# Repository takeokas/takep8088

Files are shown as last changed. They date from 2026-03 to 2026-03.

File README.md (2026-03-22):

# takep8088
8088 Single Board Computer  

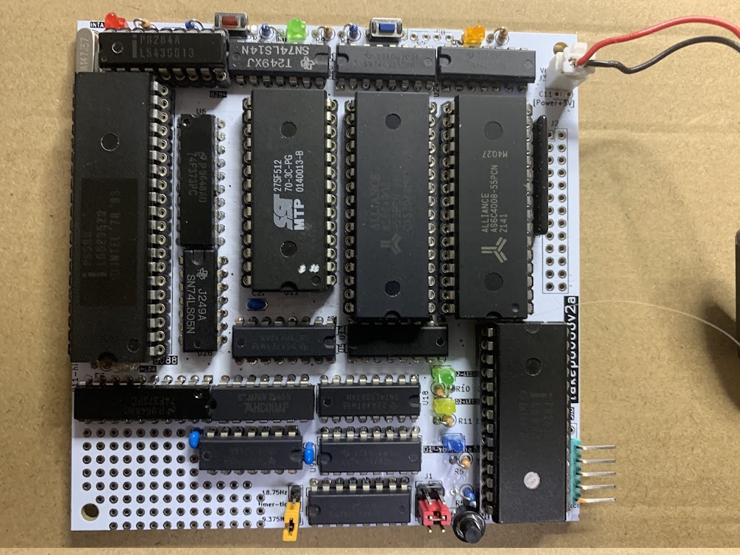
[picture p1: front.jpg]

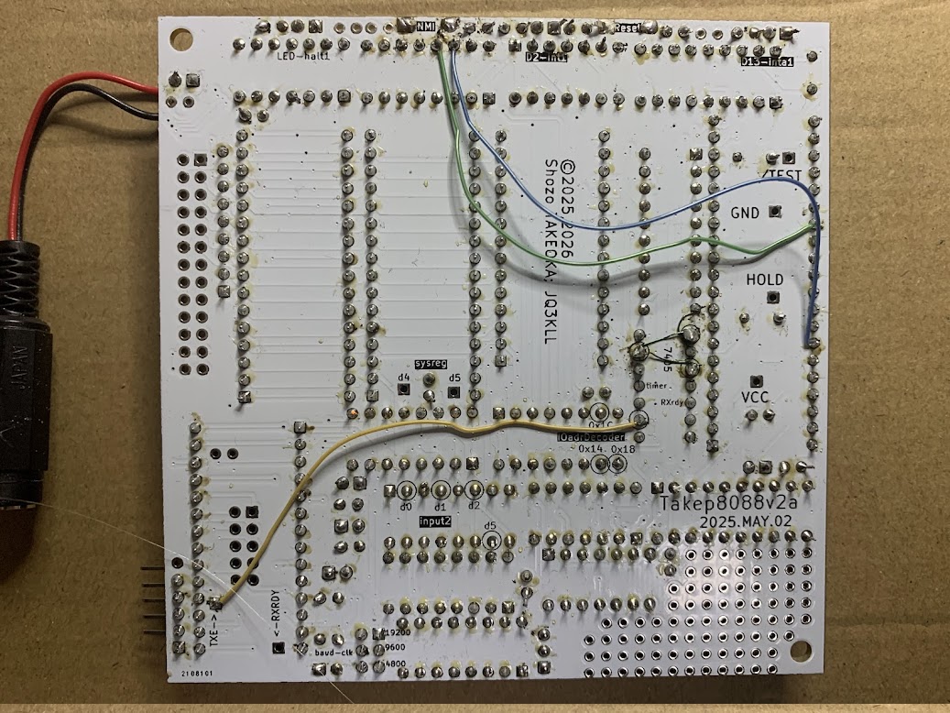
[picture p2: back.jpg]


## Spec  
- S-RAM 1MBytes  
--  全メモリ空間  
-- AS6C4008-55PCN (512KW×8bit)2チップ  
-- リセット直後は、メモリ空間の後半 512K は、ROM  
-- 出力ポートのアクセスで、後半512KをROM/RAM切り替え  

- ROM 64Bytes  
-- SST 27SF512(EEPROM)  
-- 27C512互換であれば使用可能、2764あたりからそのまま差し込めるはず  

- SIO 8251(USART)  
-- ジャンパ J1 で、ボーレート用クロックの周波数を選択可能  
-- 秋月で販売されている FTDI USBシリアル変換ケーブル(5V) が直接 差せる  
--  https://akizukidenshi.com/catalog/g/g105841/    

- フリーランニング・タイマ  
  18.75Hz / 9.375Hz を JP1 で、選択可能  

- Crystal 14.7456MHz  
-- 8251(USART) の baud rate generation に、いい感じの周波数  
-- CPU は、約 4.9MHz で動作  
-- 周辺IOのクロックは、約2.45MHz  

## ボード  


- ジャンパ J1  
-- 8251(USART)のボーレート・ジェネレータの周波数選択  
  19200/9600/4800 bps  (f/1の場合)  
  
- ジャンパ JP1  
-- フリーランニング・タイマの周期選択  
  18.75Hz / 9.375Hz

- ワイヤリング  
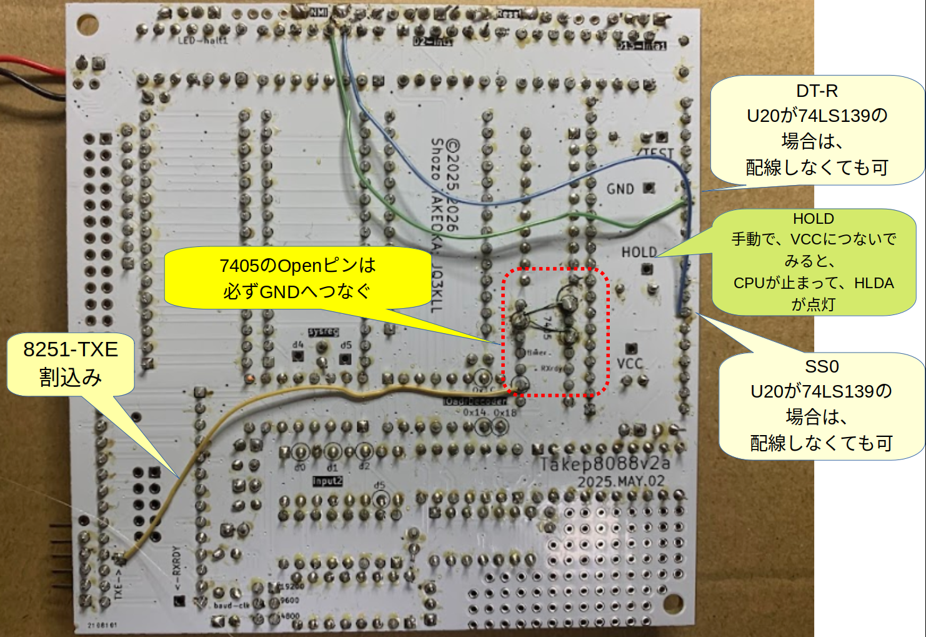
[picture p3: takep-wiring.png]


-- 8251 TX Empty割込みを使用する場合は、7405 の空き入力端子に、8251-TXE を接続する  
-- 7405 の空き入力ピンは、(手配線などで) 必ず GND へ、接続する。さもないと、Interrupt Enableした途端に、割込みが発生する。  
-- U20 74139が、74HC139 のときは、空き入力ピンを、DT-R、SS0 に接続すること。74LS139など TTL のときは、open のママでも支障ない。  

※ワイヤがあるのは、設計どおり  
-- PCBレイアウト中に、引き回しを諦めただけ…orz  

## 回路
### 7405: 割込み 要求  
-- 7405の入力は、反転されて、すべてワイアードORして反転して、8088のINT(割込み要求)に接続  
-- 7405のopenな端子は、自分で(手ハンダで?)、PullDownの必要あり  
-- 後から付けた機器からの割込み要求は、7405の空き端子に接続するとよい  

### 8251 TX Empty 割込み 要求  
-- 8251の RX割込みは、PCBで7405に接続済み  
-- 8251の TXE(empty)割込み使うよね!  
-- 自分で、7405 に配線してください ＼(^^;／  
-- PCBのレイアウトを諦めた=それが設計だっ  

### 余りゲート  
-- U1,74LS14: B(3,4),C(5,6),F(13,12)  
-- U12,74LS00: A(1,2,3),B(4,5,6)  
-- U24,74LS00: C(10,9,8),D(13,12,11)  
-- U23,74LS74: B(8-13)  

## IOポート  
###  IO port address  

   00-03 : usart0 (rw) USART レジスタ; 通常 00と01 を使用する  
   04-07 : sw1 (rd);  D0: SWの値を読む, D1: timerIRQ の確認  
   08-0B : timer-irq-clr (wr); timer IRQのクリア  
   0C-0F : sysreg (wr),D0:/rom0-ena=0でROM, 1でRAM1, D1:timer-int-ena=1でtimer割込み可, D2:led2, D3:led3  
  
   10-13 : inport2(rd),  D0: U18[2pin]=NC, D1:U18[4pin]=NC;U18=74LS367  
   14-17 :   
   18-1B :   
   1C-1F :   
   
### IO port 説明  
- sysreg (WR) 0x0C ; U5,74LS174  
-- D0: /rom0-ena (reset:0), 0:ROM0 / 1:RAM1 (メモリ空間後半 A19==1 を ROM/RAM切り替え)  
-- D1: timer-int-ena (reset:0), 0:disable / 1:enable  
-- D2: LED2 (resetで0, 点灯)  
-- D3: LED3 (resetで0, 点灯)  
-- D4: (U5 Q4)Open  
-- D5: (U5 Q5)Open  
  
- SW1 (RD) 0x04  
-- D0: SW  
-- D1 : free running timer IRQ 読み出し  
  
- timer-irq-clr  (WR) 0x08  
-- free running timer INT clear  
-- 1/(2^18) カウンタ割り込みクリア  
  
- inport2(rd) 0x10  
-- U18=74LS367  
-- D0: U18[2pin]=NC, D1:U18[4pin]=NC;  
-- D2: U18[6pin]=NC, D5:U18[10pin]=NC;   
※D3,D4 は飛ばしている(配線の困難性から)

## その他  
- HOLD を、Vcc に、手動で接続してみると、CPU の実行が停止し、HLDA LEDが点灯する  
- HOLD を使用する機器は、HOLD 端子に接続するとよい(PCB では、Pull Downしているのみ)
- 2026/MAR/20 「Kernel/VM探検隊＠つくば No3」での、発表資料  
--  https://www.slideshare.net/slideshow/tht-8088-single-board-computer-with-amd-8088-bought-at-junk-shop-in-1989/286593537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
-

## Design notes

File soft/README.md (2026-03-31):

# program loader via Xmodem  
## プログラムについて  
- nasm でアセンブル可能  
- xmodemプログラムは、fff00h に置く。ROMにはそうなるように書きこむ  
- xmodem は  
  - プログラムがスタートすると「*」を1つだけUSARTから送信  
  - ロードされるバイナリは 00400h{0040h:0000h} から置かれる  
  - ロードが終了すると、0040h:0000h 番地へ far jump {cs=0040h,pc=0000h}
- xmodem100 は  
  - プログラムがスタートすると「#」を1つだけUSARTから送信  
  - ロードされるバイナリは 00500h から置かれる  
  - ロードが終了すると、0040h:0100h 番地へ far jmp {cs=0040h,pc=0100h}
- xmodem プログラムのスタックは、020000h から、前へ伸びる  

## 使い方
- ホスト・マシンで xmodem 送信を起動後、takep8088 をリセットすると、xmodem 通信が始まる
  - 通信速度は 9600 bps。 J1 ジャンパは、真ん中(3-4)を選択  
  - 「*」または「#」がホストに送られるが、問題ない  
- xmodemが開始していない間、SW1 を押下すると、LED2 が点灯する

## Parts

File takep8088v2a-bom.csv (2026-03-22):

# | Reference | Qty | Value | Comment | 購入URL | Footprint | DNP
1 | C1, C2, C3, C4, C5, C6, C7, C8, C9 | 9 | C |  |  | Capacitor_THT:C_Disc_D3.0mm_W2.0mm_P2.50mm
2 | C10 | 1 | 10uF |  |  | Capacitor_THT:C_Disc_D3.0mm_W2.0mm_P2.50mm
3 | C11 | 1 | CP |  |  | Capacitor_THT:C_Disc_D3.4mm_W2.1mm_P2.50mm
4 | D1-rom0ena1, D2-int1, D2-LED2, D2-LED3, D11-hlda1, D13-inta1, LED-halt1 | 7 | LED |  |  | LED_THT:LED_D1.8mm_W3.3mm_H2.4mm
5 | J1 | 1 | HEADER_3x2,PH-2x3SG | USART ボーレート・ジェネレータ入力周波数 選択 | https://akizukidenshi.com/catalog/g/g116883/ | Connector_PinHeader_2.54mm:PinHeader_2x03_P2.54mm_Vertical
6 | J2 | 1 | HEADER_13x2 | IO拡張コネクタ。適当に好きなもの |  | Connector_PinHeader_2.54mm:PinHeader_2x13_P2.54mm_Vertical
7 | J2-scc0 | 1 | HEADER_6,PH-1X6RG(2) | SIOコネクタ。FTDI USBシリアル・ケーブルが適合 | https://akizukidenshi.com/catalog/g/g105336/ | Connector_PinHeader_2.54mm:PinHeader_1x06_P2.54mm_Vertical
8 | J3 | 1 | HEADER_2 | +5V電源入力。適当に好きなもの |  | Connector_PinHeader_2.54mm:PinHeader_2x01_P2.54mm_Vertical
9 | J4, J5, J6, J7, J-HOLD1, J-TEST1, J-VCC1, J-VCC2 | 8 | - | test pointなので、何も実装しない
10 | J4-scc0 | 1 | - | test pointなので、何も実装しない |  | Connector_PinHeader_2.54mm:PinHeader_2x05_P2.54mm_Vertical
11 | JP1 | 1 | HEADER_1x3,PH-1X3SG | free running timerのレート選択 | https://akizukidenshi.com/catalog/g/g103949/ | Connector_PinHeader_2.54mm:PinHeader_1x03_P2.54mm_Vertical
12 | R1, R2, R5, R12 | 4 | R,10K |  |  | Resistor_THT:R_Axial_DIN0207_L6.3mm_D2.5mm_P2.54mm_Vertical
13 | R3, R4 | 2 | R,4.7K |  |  | Resistor_THT:R_Axial_DIN0204_L3.6mm_D1.6mm_P5.08mm_Horizontal
14 | R6, R7, R8, R9, R10, R11, R13 | 7 | R,330 |  |  | Resistor_THT:R_Axial_DIN0207_L6.3mm_D2.5mm_P2.54mm_Vertical
15 | RN1 | 1 | R_Network08 |  |  | Resistor_THT:R_Array_SIP9
16 | SW1 | 1 | TVBP06-B043CU-B | Reset | https://akizukidenshi.com/catalog/g/g108214/ | Button_Switch_THT:SW_PUSH_1P1T_6x3.5mm_H5.0_APEM_MJTP1250
17 | SW2 | 1 | TVBP06-B043CU-B | NMI_SW | https://akizukidenshi.com/catalog/g/g108214/ | Button_Switch_THT:SW_PUSH_1P1T_6x3.5mm_H5.0_APEM_MJTP1250
18 | U1 | 1 | 74LS14 |  |  | Package_DIP:DIP-14_W7.62mm
19 | U2, U6 | 2 | 74LS373 |  |  | Package_DIP:DIP-20_W7.62mm
20 | U3 | 1 | 8088 |  | https://wakamatsu.biz/products/detail/455907 | Package_DIP:DIP-40_W15.24mm_Socket
21 | U4, U7 | 2 | AS6C4008 | Aliexpressで買っても、およそ大丈夫 |  | Package_DIP:DIP-32_W15.24mm
22 | U5 | 1 | 74LS174 | 74HC174でも可 |  | Package_DIP:DIP-16_W7.62mm
23 | U8 | 1 | 8251A |  |  | Package_DIP:DIP-28_W15.24mm
24 | U9, U10 | 2 | 4040 |  |  | Package_DIP:DIP-16_W7.62mm
25 | U11 | 1 | 27C512 |  |  | Package_DIP:DIP-28_W15.24mm
26 | U12, U14 | 2 | 74HC00
27 | U13 | 1 | 74LS138 |  |  | Package_DIP:DIP-16_W7.62mm
28 | U15 | 1 | 8284 |  | https://wakamatsu.biz/products/detail/456508 | Package_DIP:DIP-18_W7.62mm
29 | U18 | 1 | 74LS367 |  |  | Package_DIP:DIP-16_W7.62mm
30 | U20 | 1 | 74LS139 | 一部入力ピンがopenなので、必ずLS。または、「役立たない配線」をするなら、LSでも可 |  | Package_DIP:DIP-16_W7.62mm
31 | U23 | 1 | 74HC74 |  |  | Package_DIP:DIP-14_W7.62mm
32 | U26 | 1 | 74LS05 | HCでも可。LSであっても、空き入力ピンは、必ずLoにすること。 |  | Package_DIP:DIP-14_W7.62mm
33 | Y1 | 1 | Crystal,14.7456MHz |  |  | Crystal:Crystal_HC49-4H_Vertical
34 | U24 | 1 | 74LS00 | 一部入力ピンがopenなので、必ずLS
35 | J6-SW1 | 1 |  | 適当なスイッチを無理やり取付ける

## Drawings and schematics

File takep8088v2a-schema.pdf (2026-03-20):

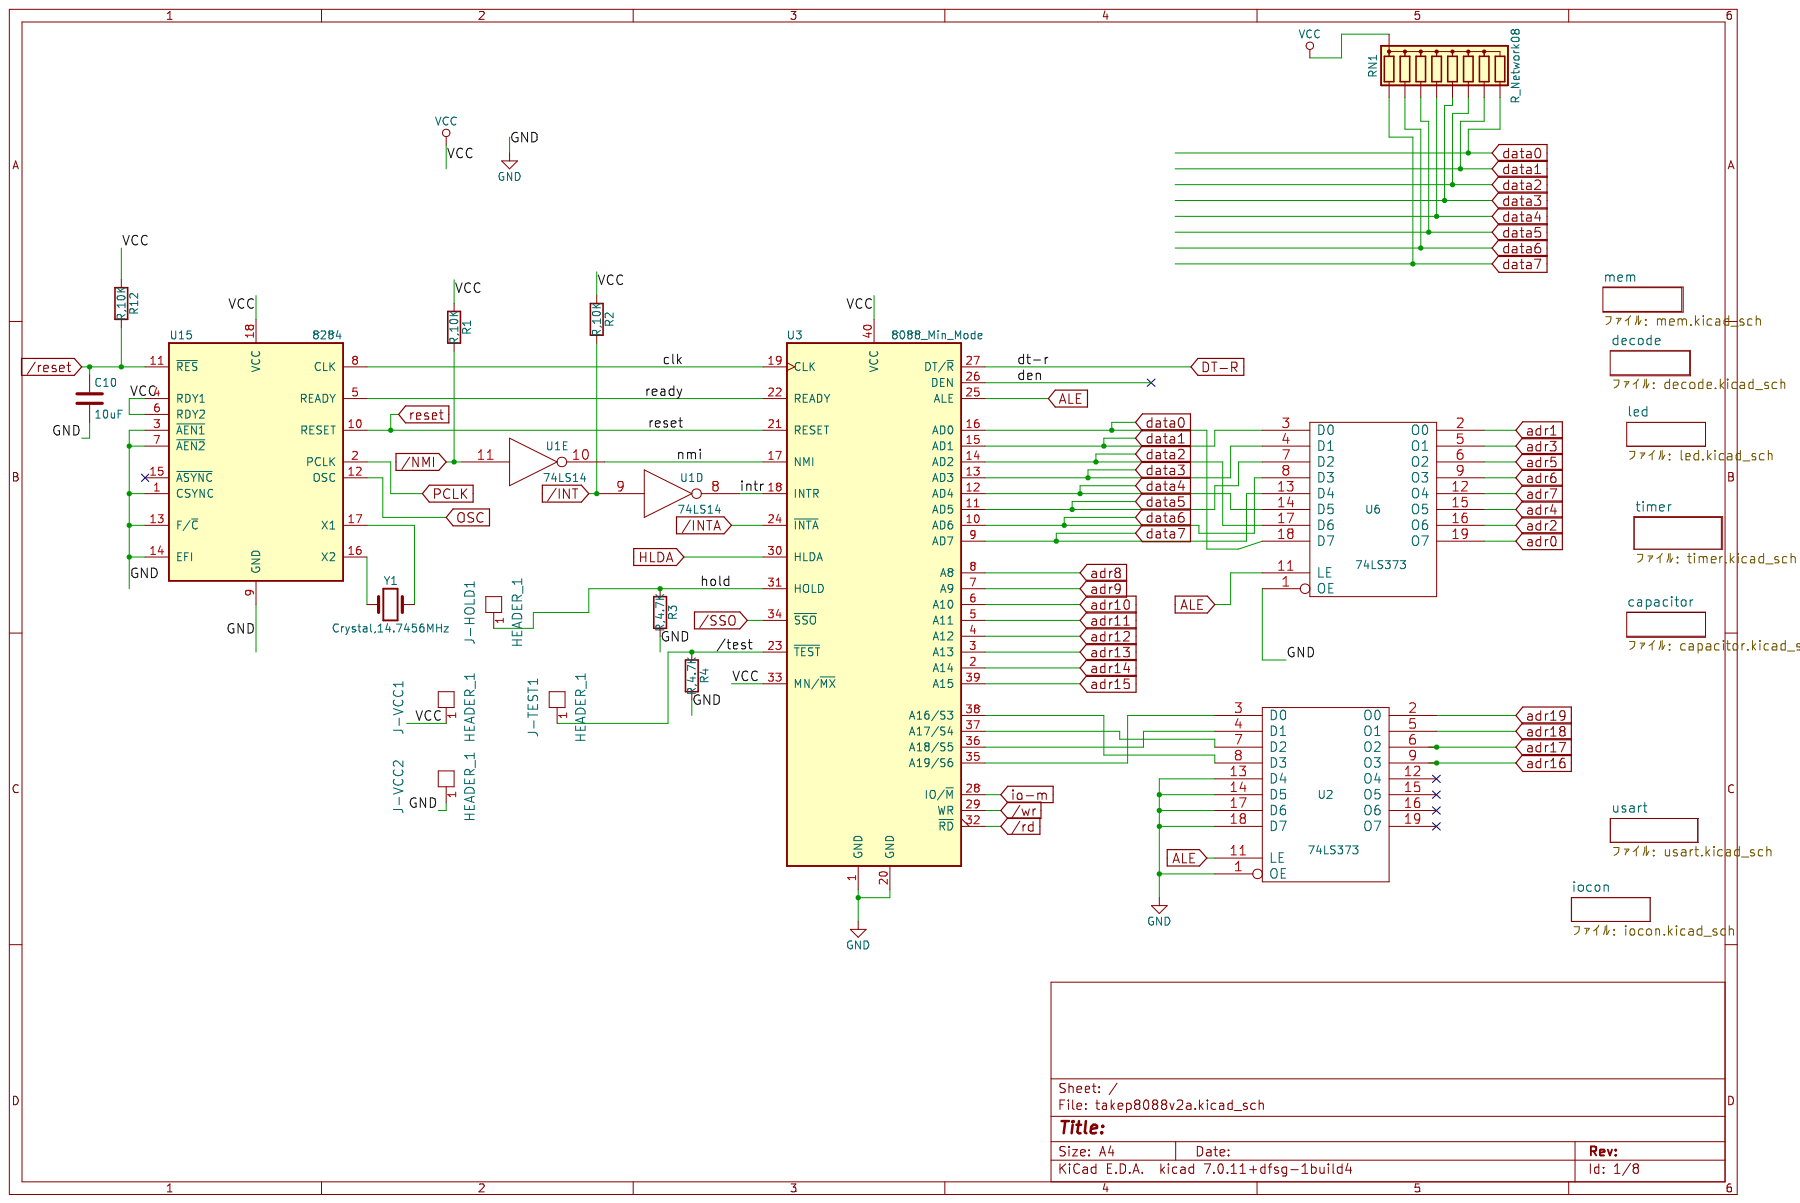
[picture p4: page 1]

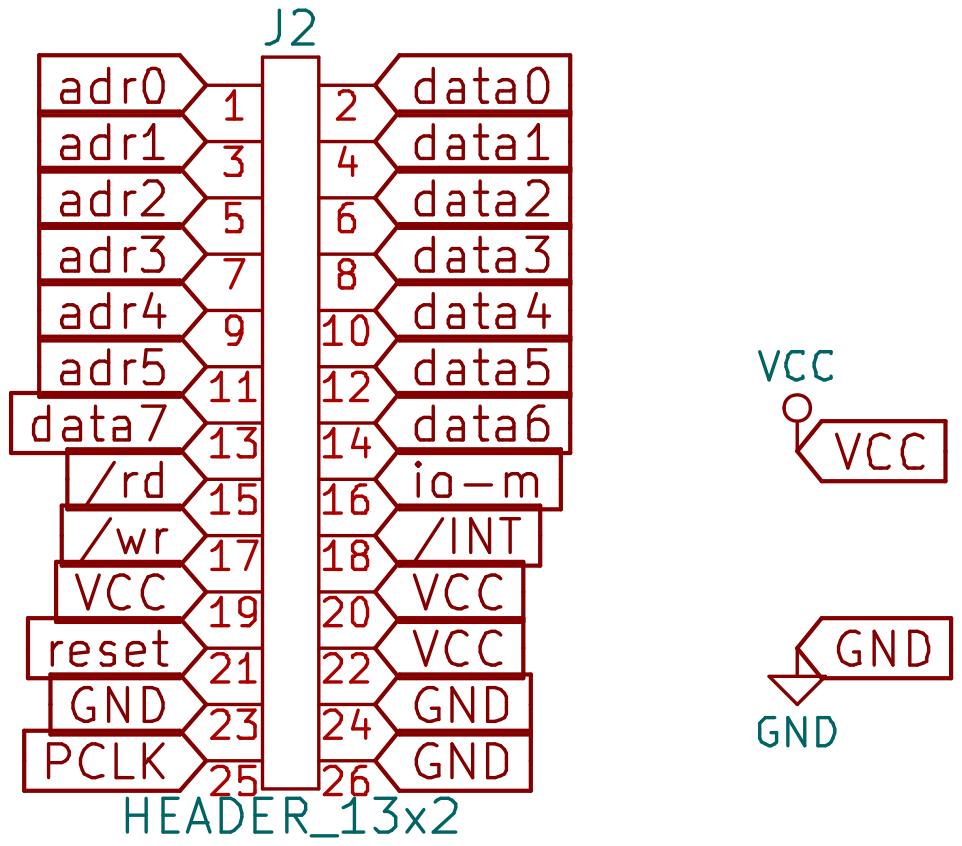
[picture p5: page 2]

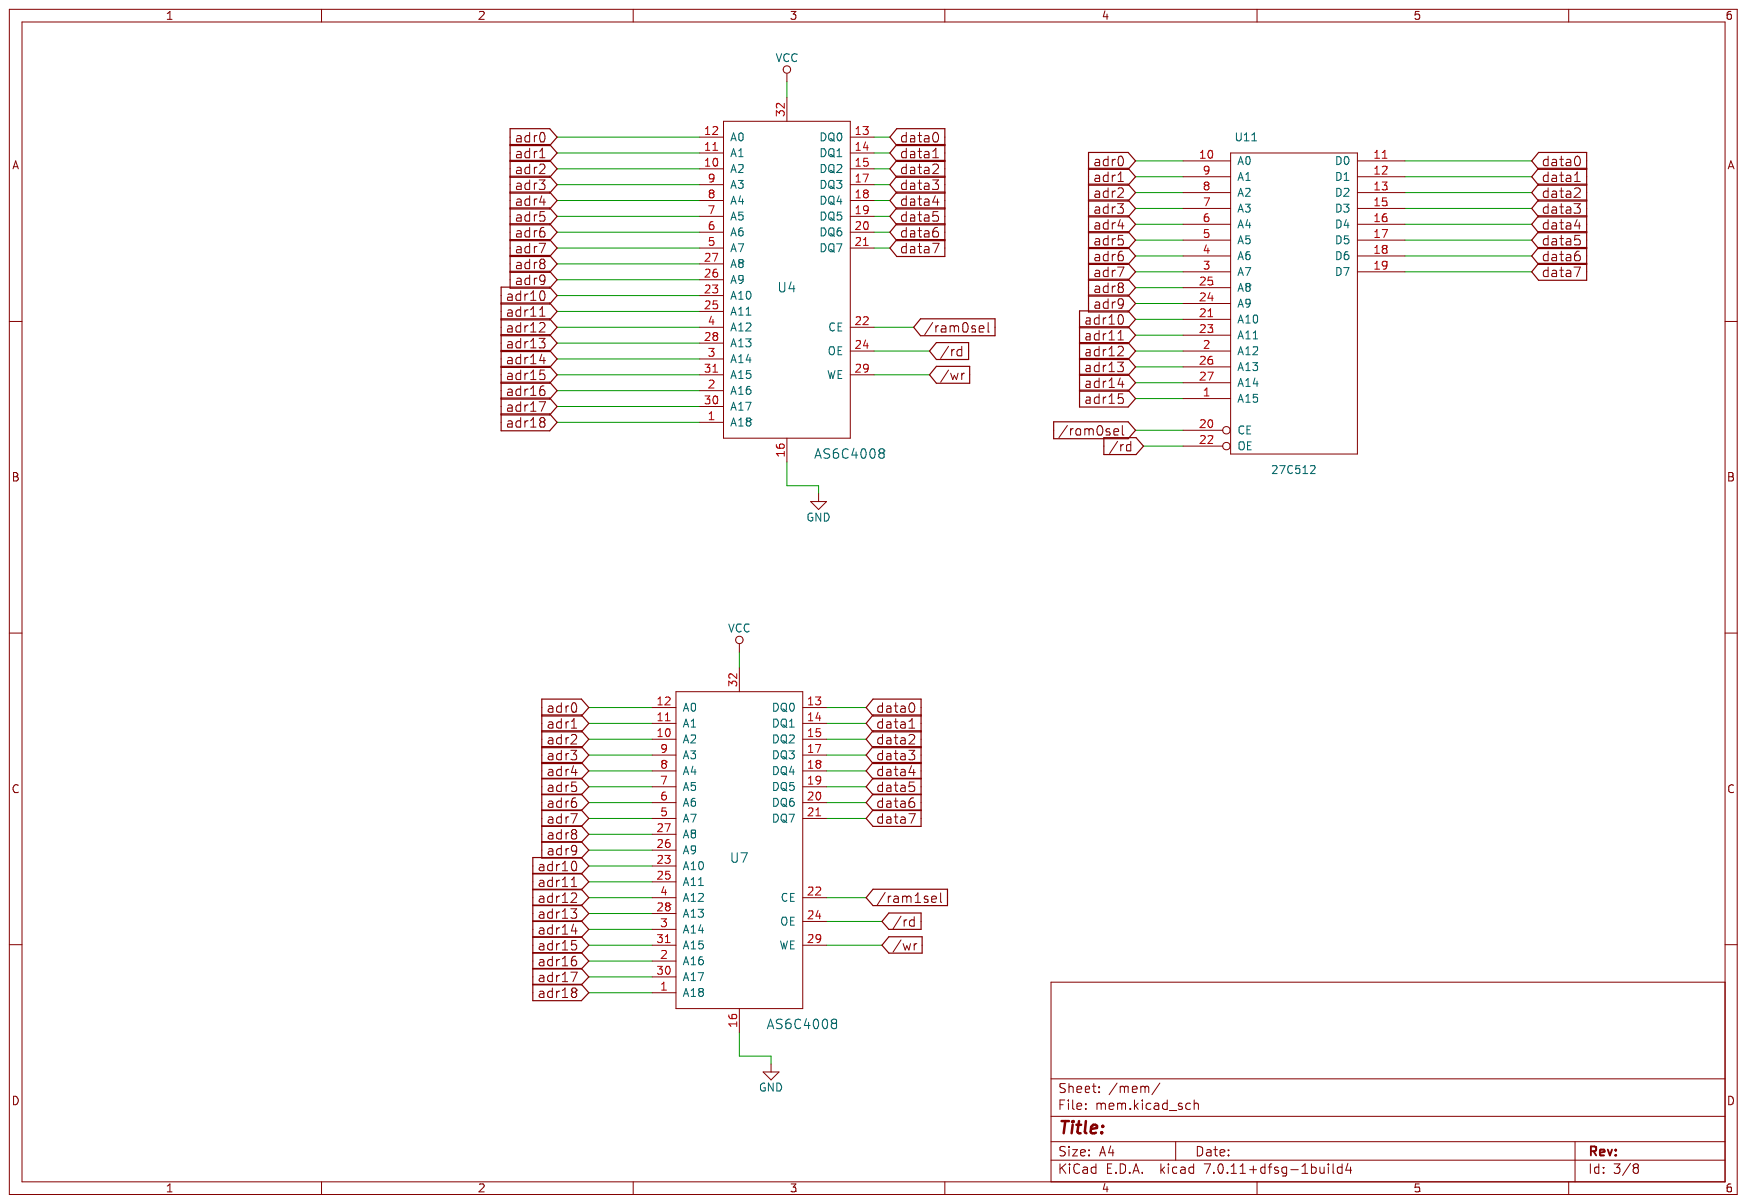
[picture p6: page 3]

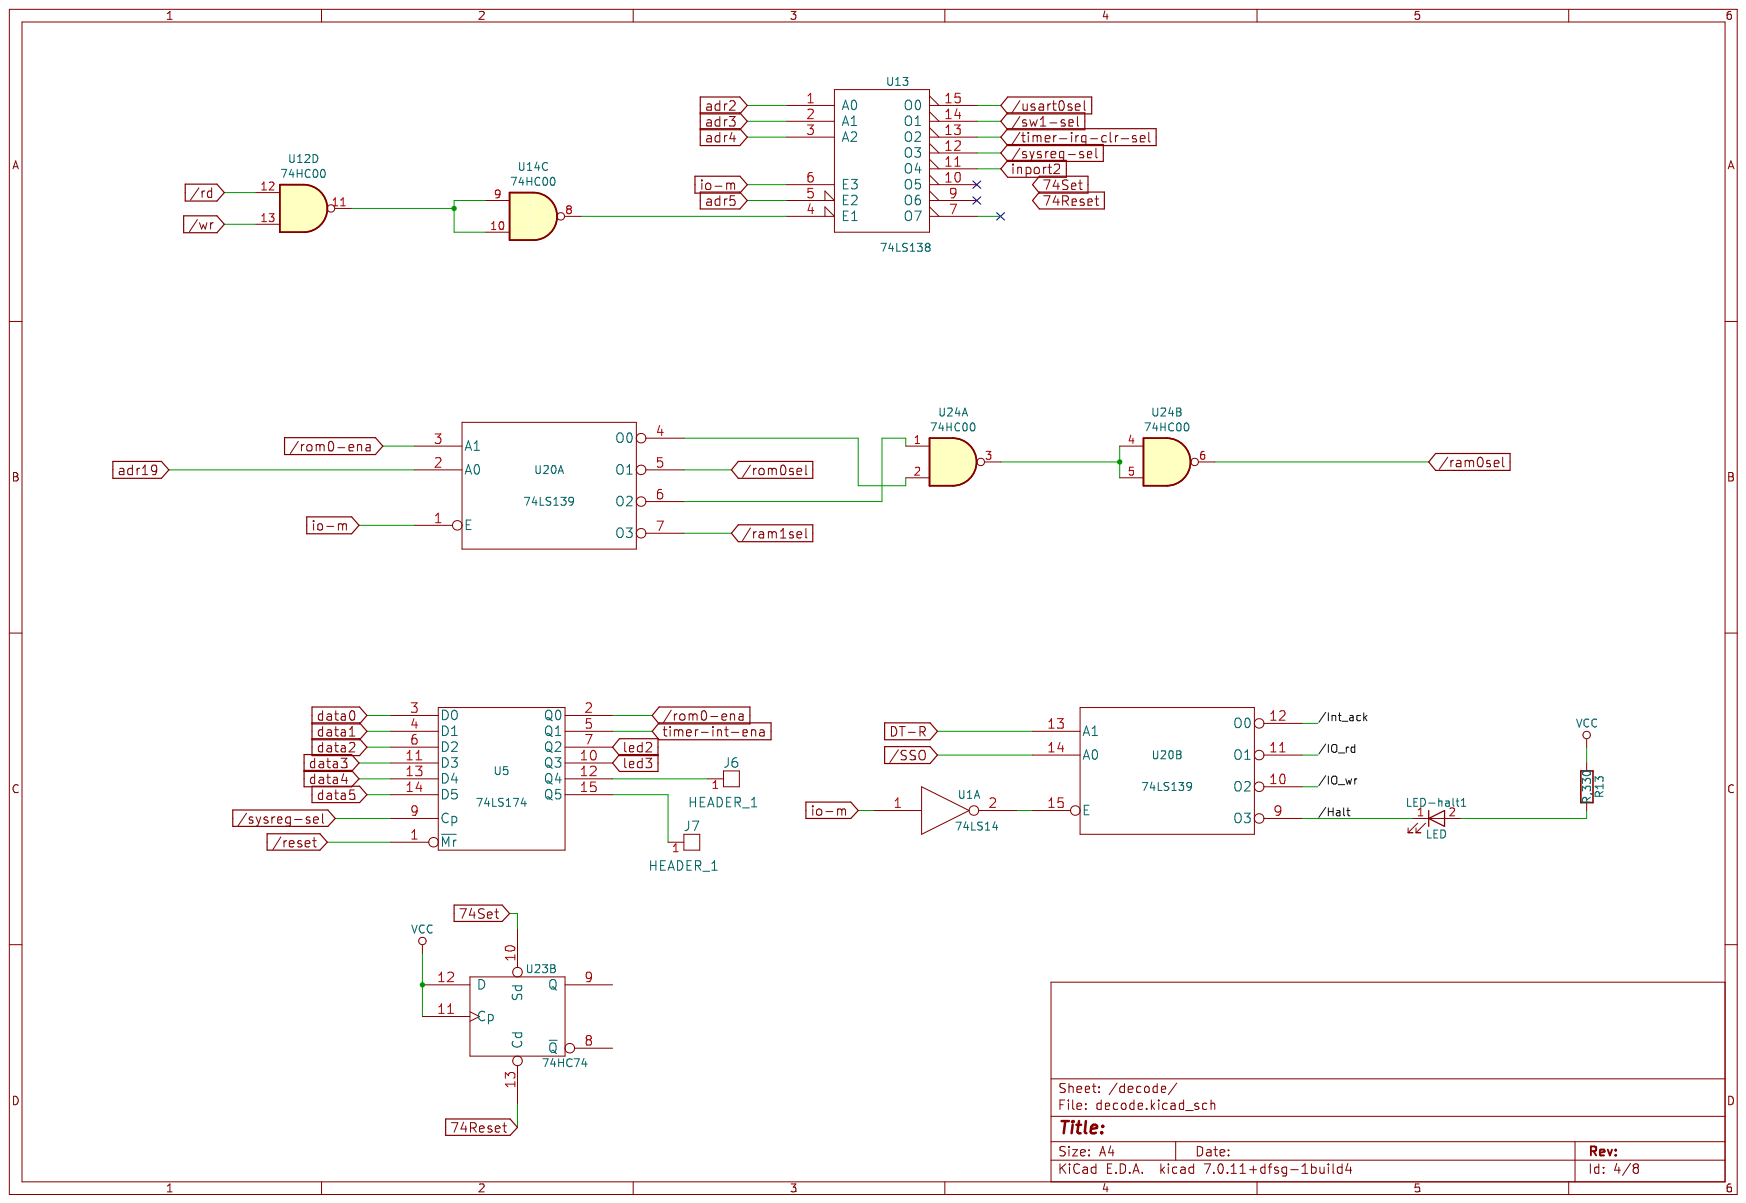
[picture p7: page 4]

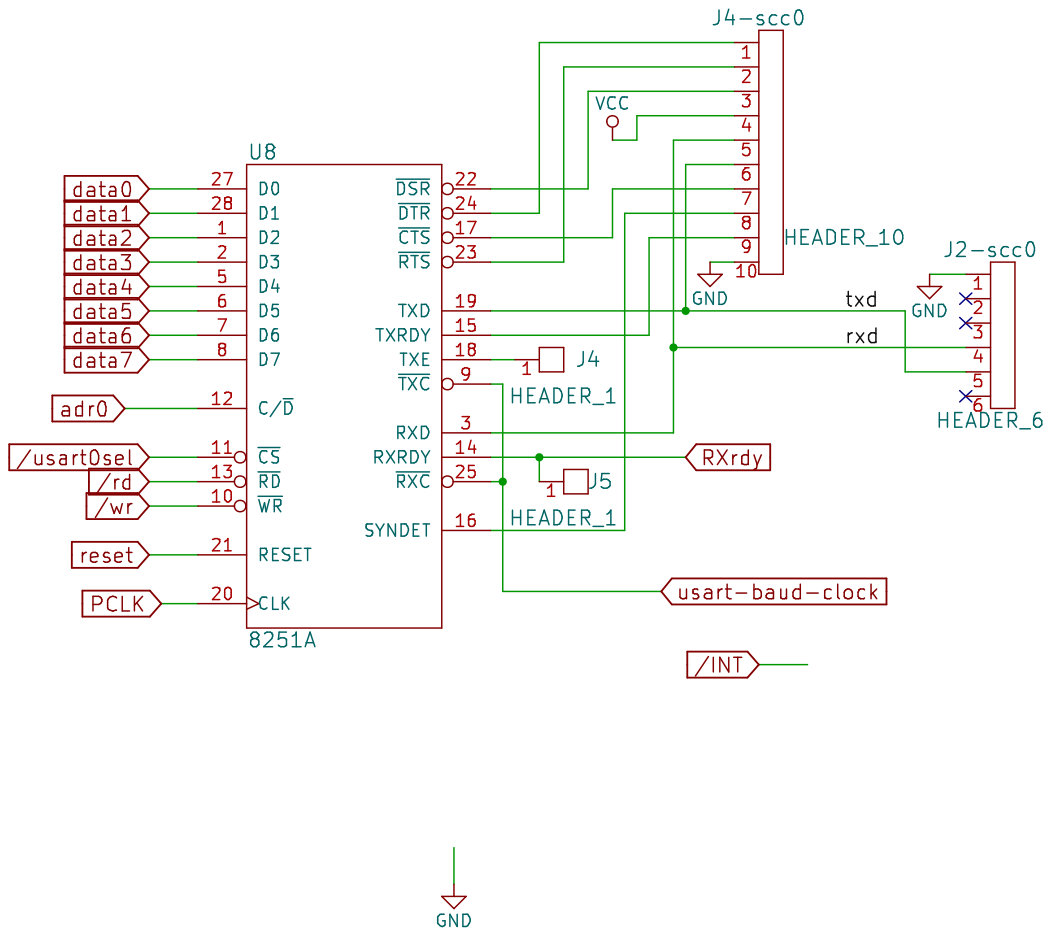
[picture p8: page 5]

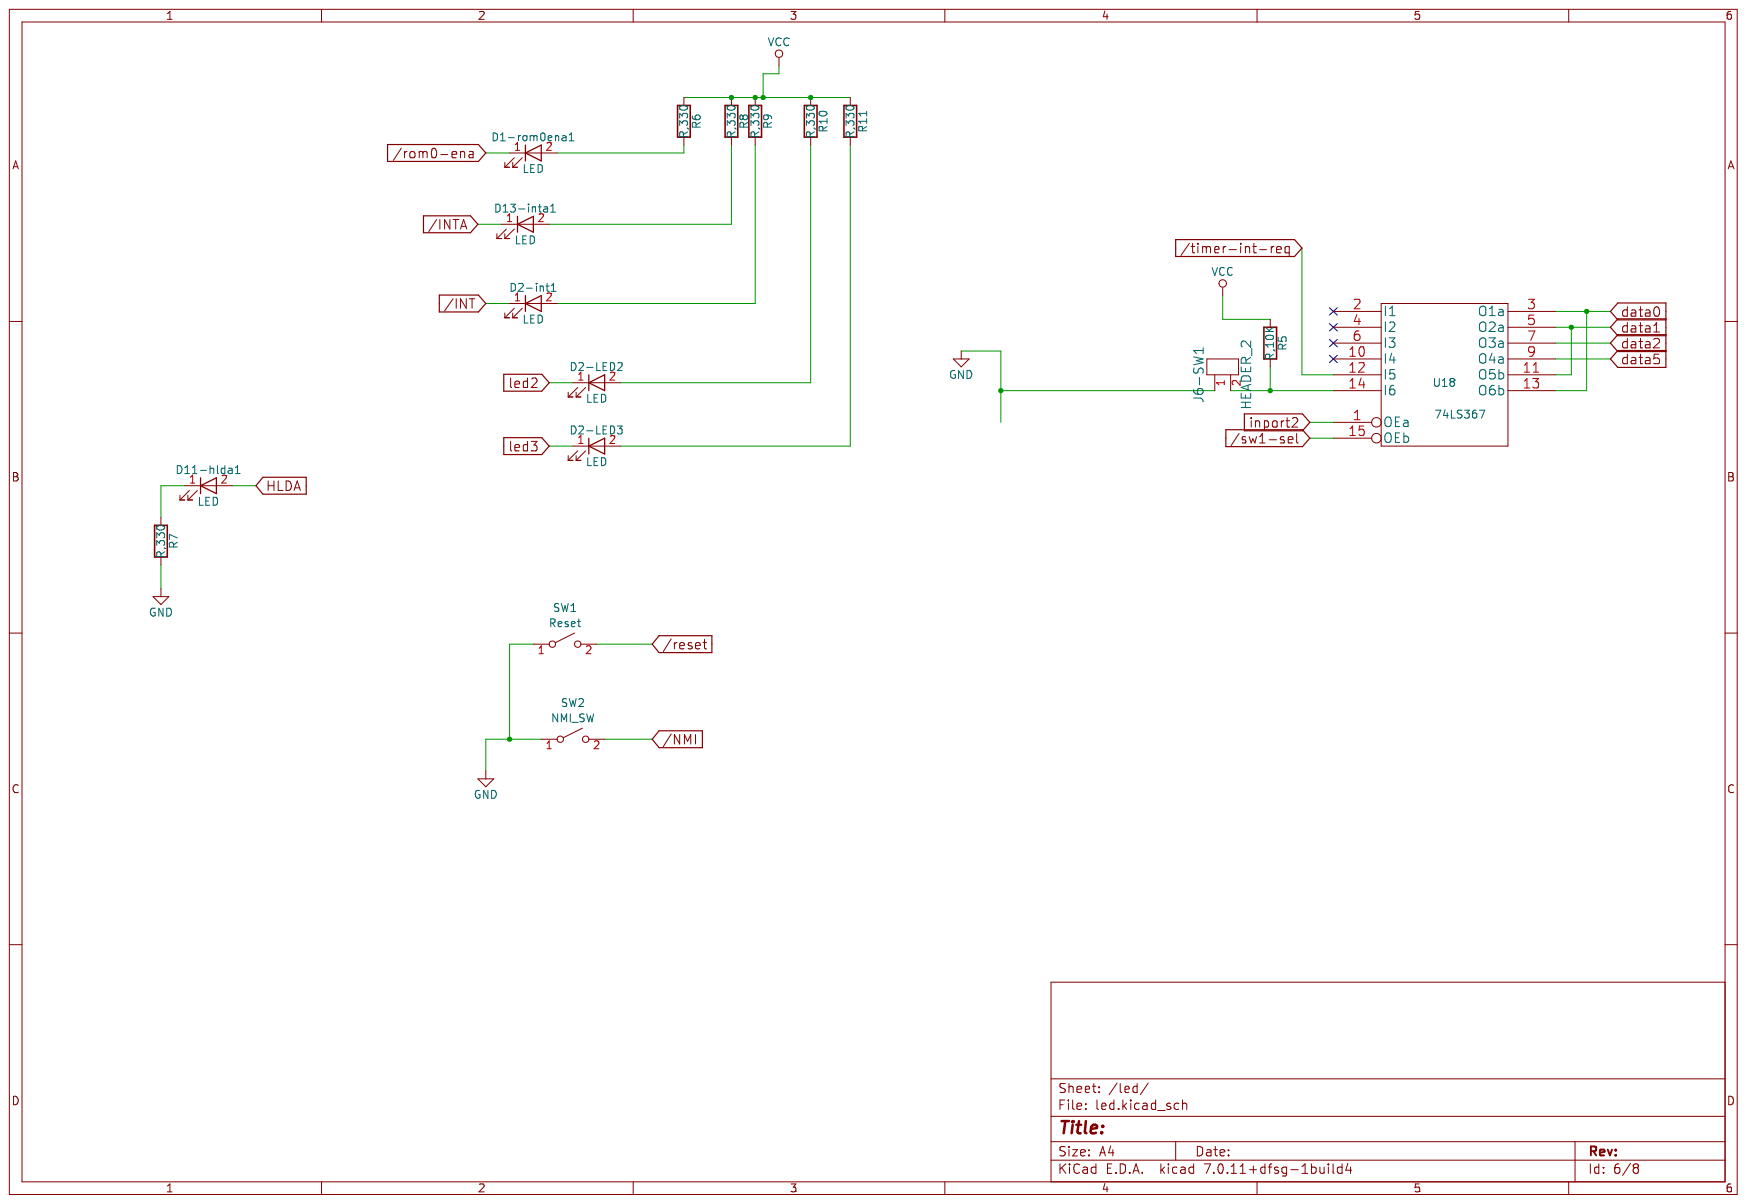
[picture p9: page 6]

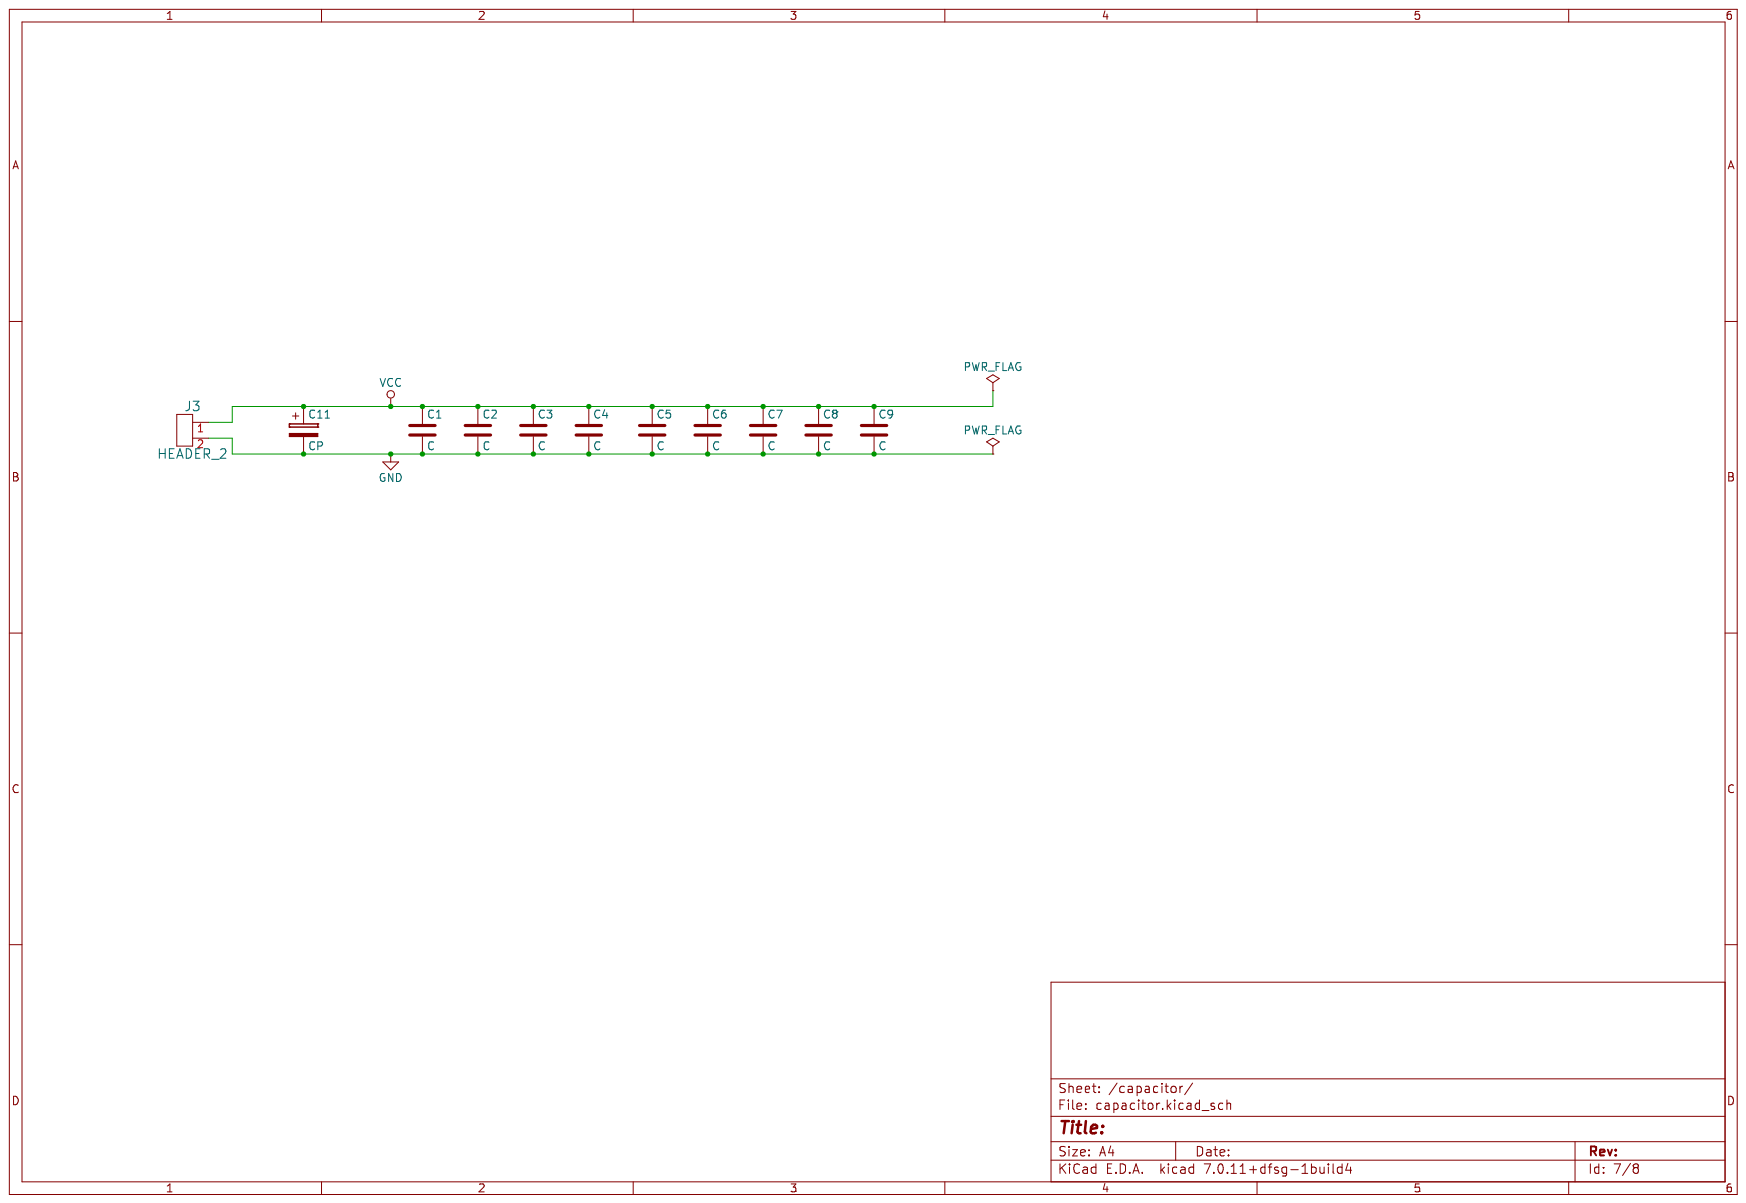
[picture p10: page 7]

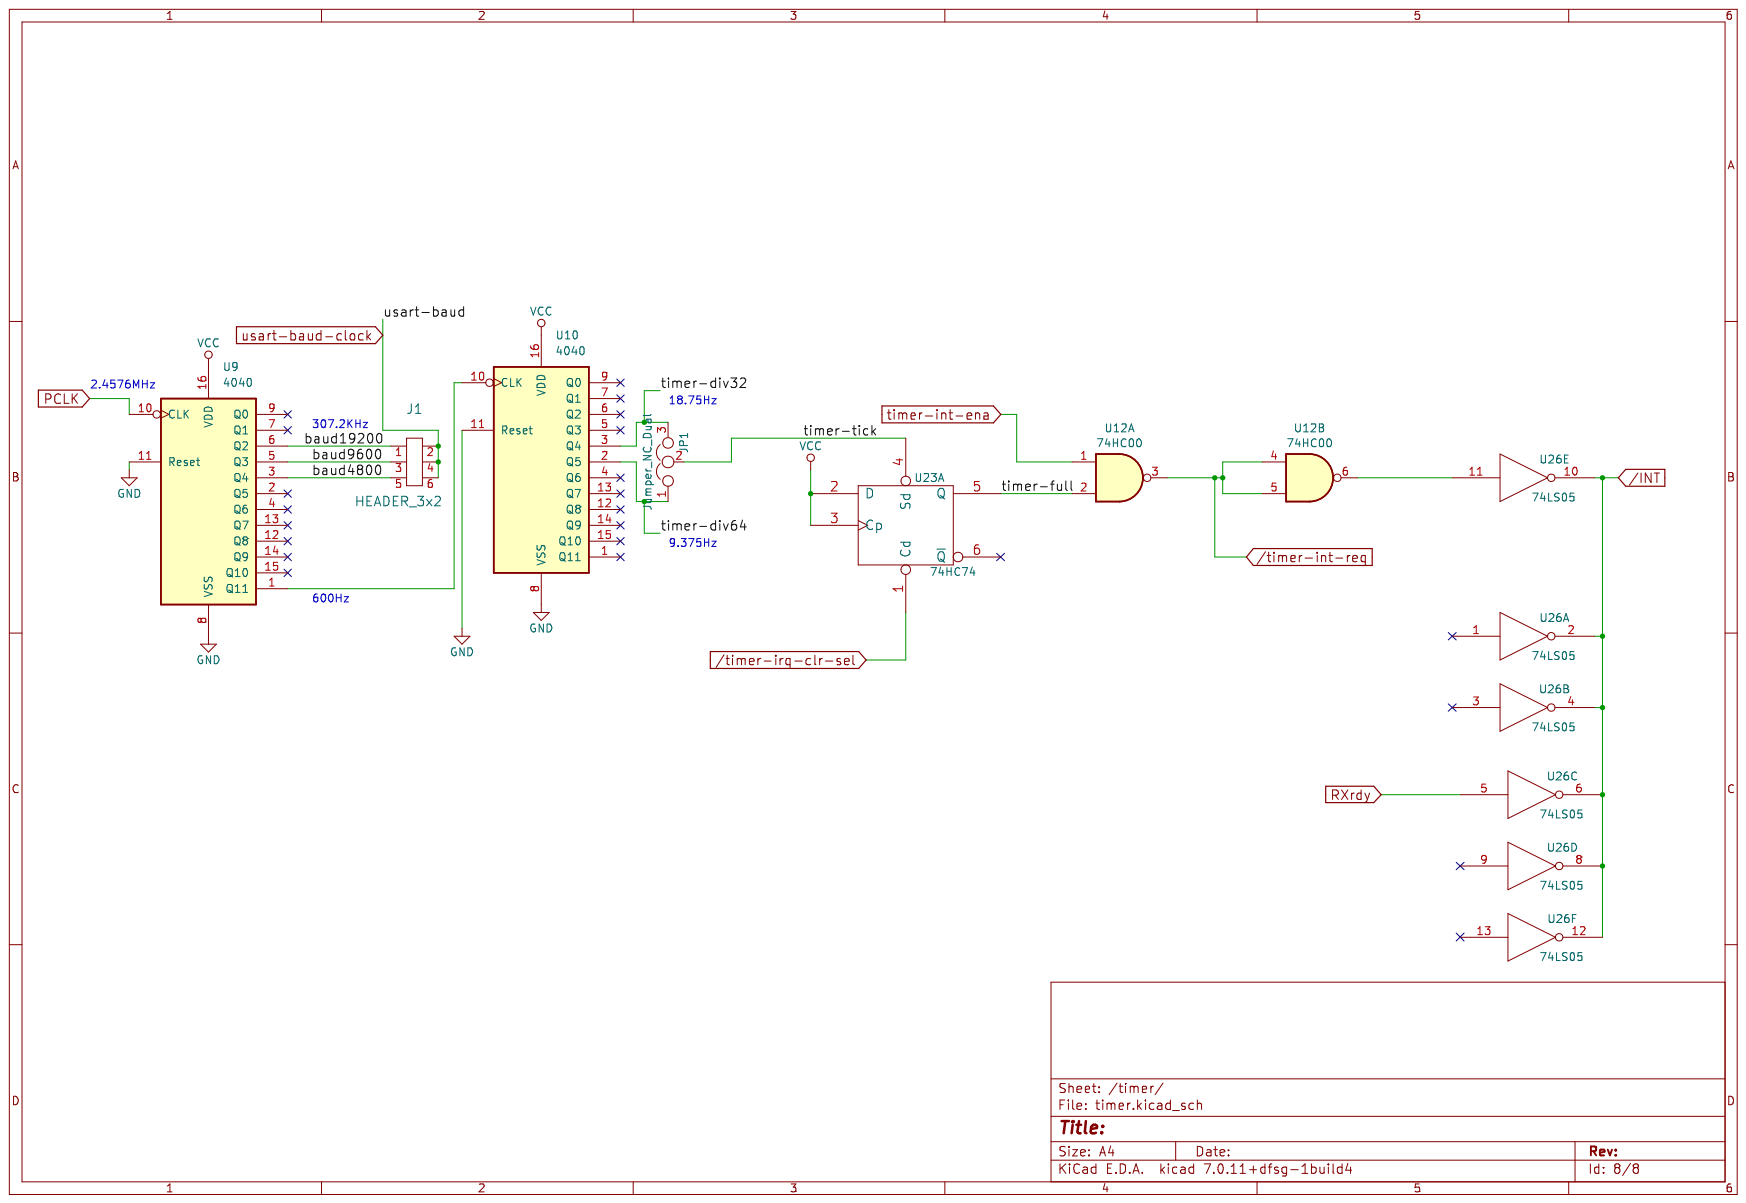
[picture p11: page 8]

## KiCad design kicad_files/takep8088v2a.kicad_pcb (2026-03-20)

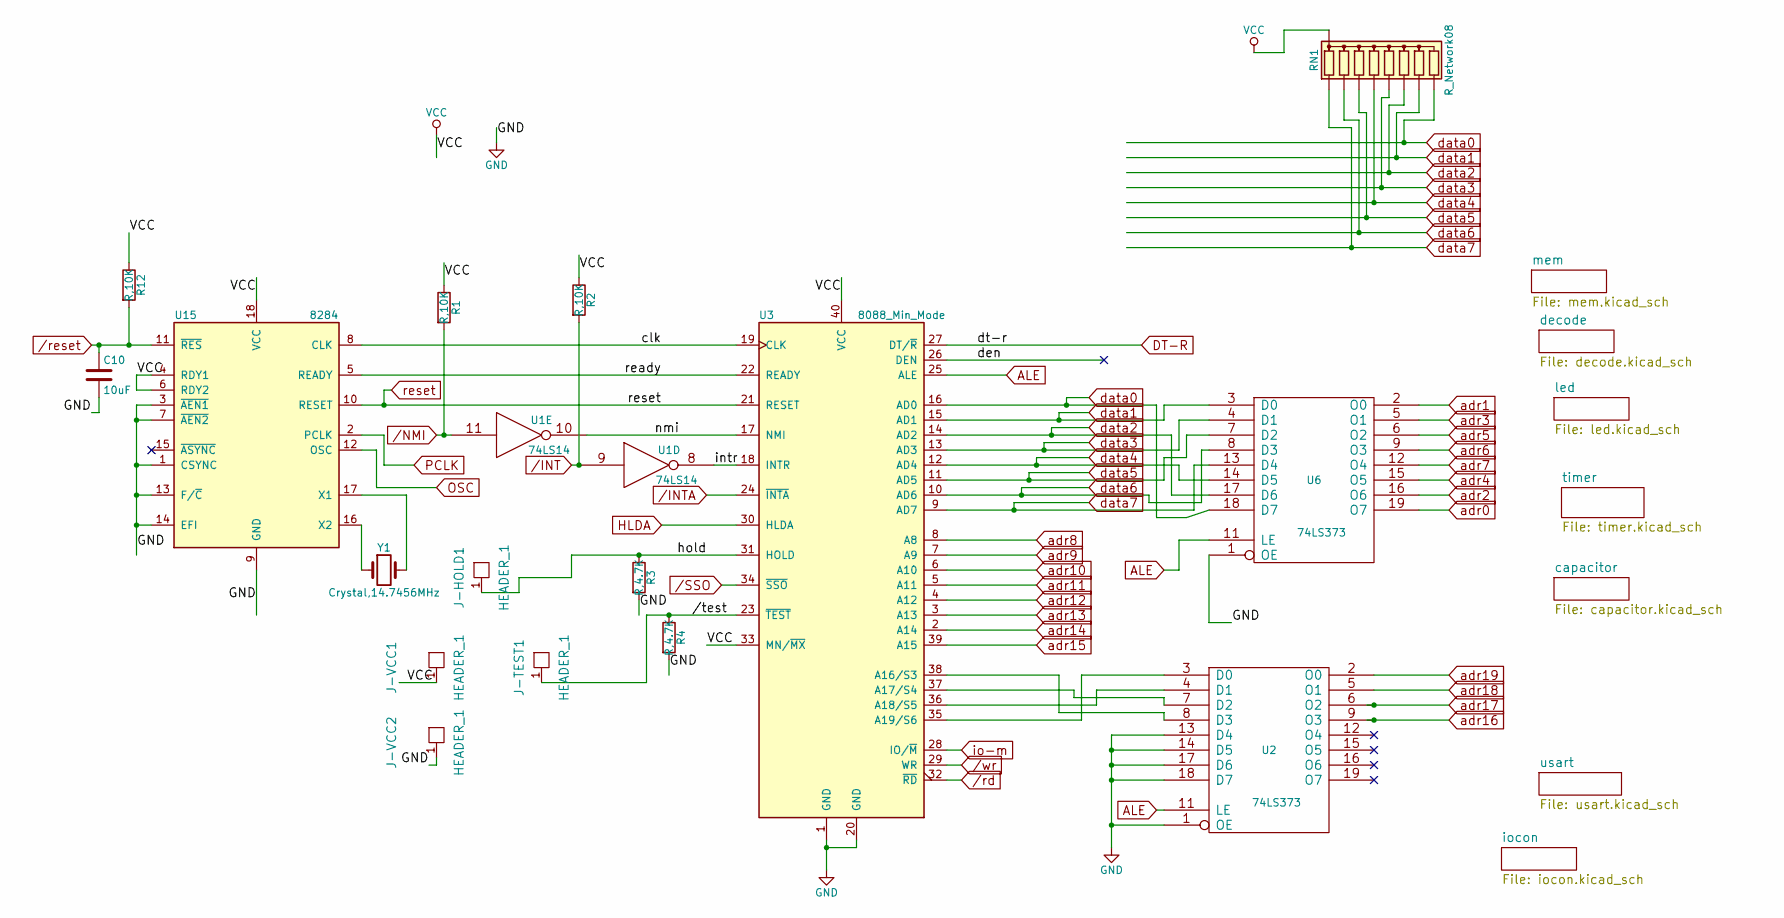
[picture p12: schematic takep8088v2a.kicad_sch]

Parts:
C10: 10uF; C_Disc_D3.0mm_W2.0mm_P2.50mm
J-HOLD1: HEADER_1; PinHeader_1x01_P2.54mm_Vertical
J-TEST1: HEADER_1; PinHeader_1x01_P2.54mm_Vertical
J-VCC1, J-VCC2: HEADER_1; PinHeader_1x01_P2.54mm_Vertical
R1, R2, R12: R,10K; R_Axial_DIN0207_L6.3mm_D2.5mm_P2.54mm_Vertical
R3, R4: R,4.7K; R_Axial_DIN0204_L3.6mm_D1.6mm_P5.08mm_Horizontal
RN1: R_Network08; R_Array_SIP9
U1: 74LS14; DIP-14_W7.62mm
U2, U6: 74LS373; DIP-20_W7.62mm
U3: 8088_Min_Mode; DIP-40_W15.24mm_Socket
U15: 8284; DIP-18_W7.62mm
Y1: Crystal,14.7456MHz; Crystal_HC49-4H_Vertical

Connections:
/clk: U3.19 (CLK), U15.8 (CLK)
/den: U3.26 (DEN)
/hold: J-HOLD1.1, R3.1, U3.31 (HOLD)
/intr: U1.8, U3.18 (INTR)
/nmi: U1.10, U3.17 (NMI)
/ready: U3.22 (READY), U15.5 (READY)
//test: J-TEST1.1, R4.1, U3.23 (~TEST)
ALE: U2.11 (LE), U3.25 (ALE), U6.11 (LE)
DT-R: U3.27 (DT/~R); also elsewhere on the board
GND: C10.2, J-VCC2.1, R3.2, R4.2, U1.7 (GND), U2.1 (OE), U2.10 (GND), U2.13 (D4), U2.14 (D5), U2.17 (D6), U2.18 (D7), U3.1 (GND), U3.20 (GND), U6.1 (OE), U6.10 (GND), U15.1 (CSYNC), U15.3 (~AEN1), U15.7 (~AEN2), U15.9 (GND), U15.13 (F/~C), U15.14 (EFI); also elsewhere on the board
HLDA: U3.30 (HLDA); also elsewhere on the board
unnamed: U2.3 (D0), U3.35 (A19/S6)
unnamed: U2.4 (D1), U3.36 (A18/S5)
unnamed: U2.7 (D2), U3.37 (A17/S4)
unnamed: U2.8 (D3), U3.38 (A16/S3)
unnamed: U15.17 (X1), Y1.2
unnamed: U15.16 (X2), Y1.1
OSC: U15.12 (OSC)
PCLK: U15.2 (PCLK); also elsewhere on the board
VCC: J-VCC1.1, R1.1, R2.1, R12.1, RN1.1 (common), U1.14 (VCC), U2.20 (VCC), U3.33 (MN/~MX), U3.40 (VCC), U6.20 (VCC), U15.4 (RDY1), U15.6 (RDY2), U15.18 (VCC); also elsewhere on the board
adr0: U6.19 (O7); also elsewhere on the board
adr1: U6.2 (O0); also elsewhere on the board
adr2: U6.16 (O6); also elsewhere on the board
adr3: U6.5 (O1); also elsewhere on the board
adr4: U6.15 (O5); also elsewhere on the board
adr5: U6.6 (O2); also elsewhere on the board
adr6: U6.9 (O3); also elsewhere on the board
adr7: U6.12 (O4); also elsewhere on the board
adr8: U3.8 (A8); also elsewhere on the board
adr9: U3.7 (A9); also elsewhere on the board
adr10: U3.6 (A10); also elsewhere on the board
adr11: U3.5 (A11); also elsewhere on the board
adr12: U3.4 (A12); also elsewhere on the board
adr13: U3.3 (A13); also elsewhere on the board
adr14: U3.2 (A14); also elsewhere on the board
adr15: U3.39 (A15); also elsewhere on the board
adr16: U2.9 (O3); also elsewhere on the board
adr17: U2.6 (O2); also elsewhere on the board
adr18: U2.5 (O1); also elsewhere on the board
adr19: U2.2 (O0); also elsewhere on the board
data0: RN1.9 (R8), U3.16 (AD0), U6.18 (D7); also elsewhere on the board
data1: RN1.8 (R7), U3.15 (AD1), U6.3 (D0); also elsewhere on the board
data2: RN1.7 (R6), U3.14 (AD2), U6.17 (D6); also elsewhere on the board
data3: RN1.6 (R5), U3.13 (AD3), U6.4 (D1); also elsewhere on the board
data4: RN1.5 (R4), U3.12 (AD4), U6.14 (D5); also elsewhere on the board
data5: RN1.4 (R3), U3.11 (AD5), U6.7 (D2); also elsewhere on the board
data6: RN1.3 (R2), U3.10 (AD6), U6.8 (D3); also elsewhere on the board
data7: RN1.2 (R1), U3.9 (AD7), U6.13 (D4); also elsewhere on the board
io-m: U3.28 (IO/~M); also elsewhere on the board
reset: U3.21 (RESET), U15.10 (RESET); also elsewhere on the board
/INT: R2.2, U1.9; also elsewhere on the board
/INTA: U3.24 (~INTA); also elsewhere on the board
/NMI: R1.2, U1.11; also elsewhere on the board
/SSO: U3.34 (~SSO); also elsewhere on the board
/rd: U3.32 (~RD); also elsewhere on the board
/reset: C10.1, R12.2, U15.11 (~RES); also elsewhere on the board
/wr: U3.29 (WR); also elsewhere on the board

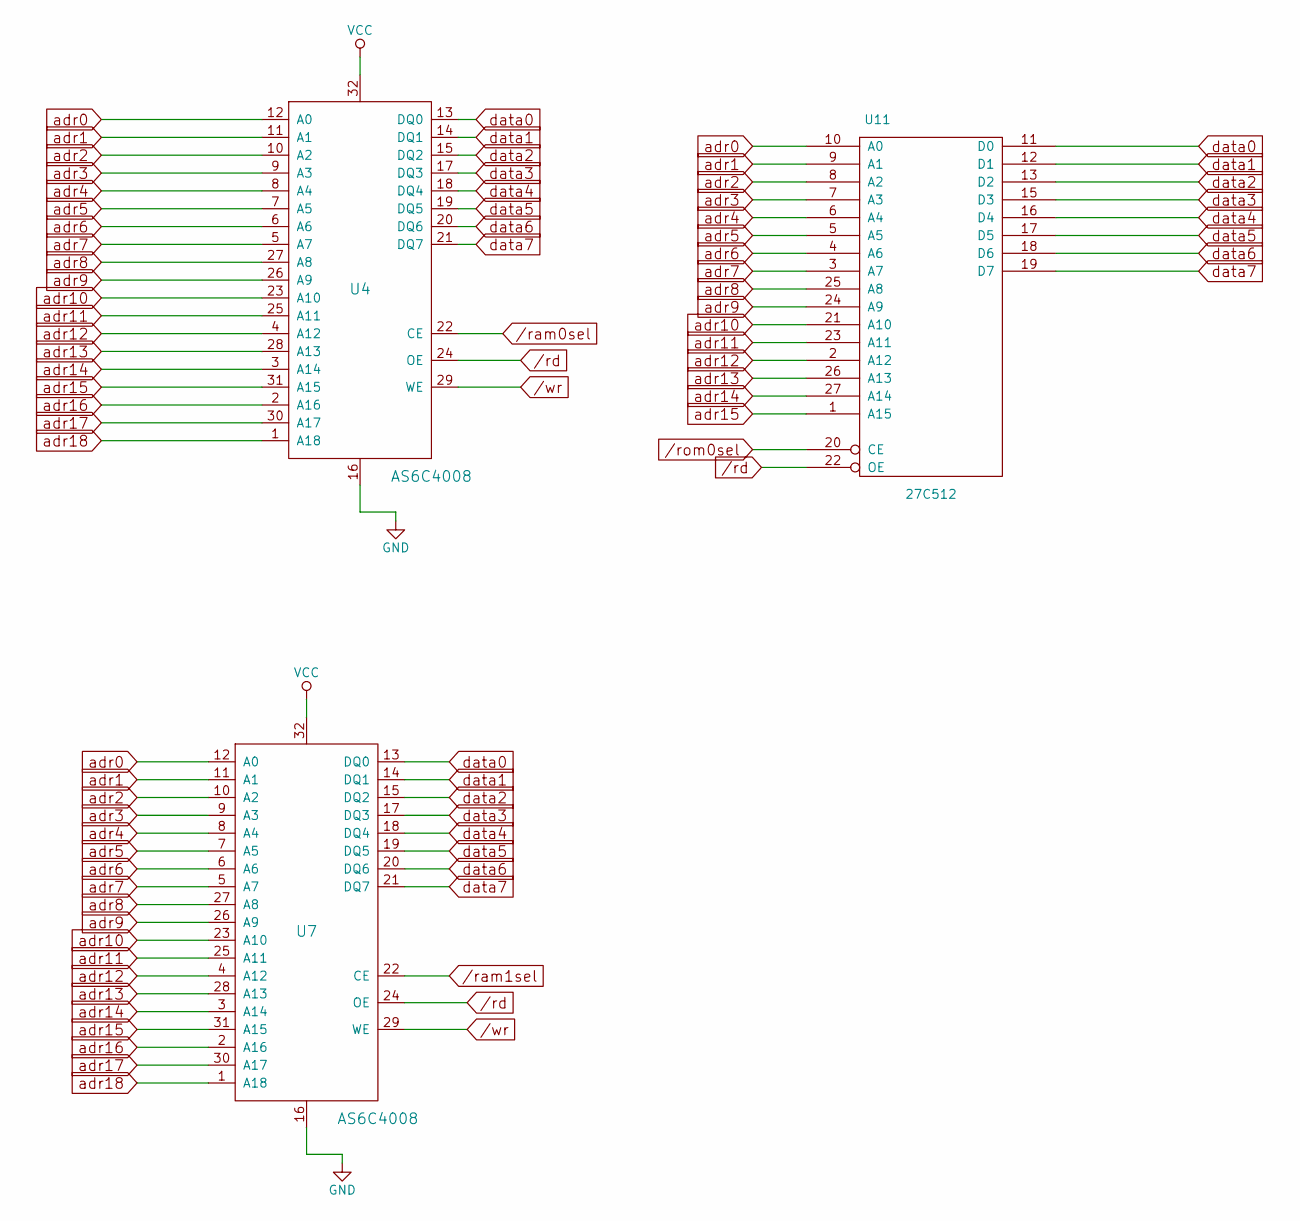
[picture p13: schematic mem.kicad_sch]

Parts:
U4, U7: AS6C4008; DIP-32_W15.24mm
U11: 27C512; DIP-28_W15.24mm

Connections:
GND: U4.16, U7.16, U11.14 (GND); also elsewhere on the board
VCC: U4.32, U7.32, U11.28 (VCC); also elsewhere on the board
adr0: U4.12 (A0), U7.12 (A0), U11.10 (A0); also elsewhere on the board
adr1: U4.11 (A1), U7.11 (A1), U11.9 (A1); also elsewhere on the board
adr2: U4.10 (A2), U7.10 (A2), U11.8 (A2); also elsewhere on the board
adr3: U4.9 (A3), U7.9 (A3), U11.7 (A3); also elsewhere on the board
adr4: U4.8 (A4), U7.8 (A4), U11.6 (A4); also elsewhere on the board
adr5: U4.7 (A5), U7.7 (A5), U11.5 (A5); also elsewhere on the board
adr6: U4.6 (A6), U7.6 (A6), U11.4 (A6); also elsewhere on the board
adr7: U4.5 (A7), U7.5 (A7), U11.3 (A7); also elsewhere on the board
adr8: U4.27 (A8), U7.27 (A8), U11.25 (A8); also elsewhere on the board
adr9: U4.26 (A9), U7.26 (A9), U11.24 (A9); also elsewhere on the board
adr10: U4.23 (A10), U7.23 (A10), U11.21 (A10); also elsewhere on the board
adr11: U4.25 (A11), U7.25 (A11), U11.23 (A11); also elsewhere on the board
adr12: U4.4 (A12), U7.4 (A12), U11.2 (A12); also elsewhere on the board
adr13: U4.28 (A13), U7.28 (A13), U11.26 (A13); also elsewhere on the board
adr14: U4.3 (A14), U7.3 (A14), U11.27 (A14); also elsewhere on the board
adr15: U4.31 (A15), U7.31 (A15), U11.1 (A15); also elsewhere on the board
adr16: U4.2 (A16), U7.2 (A16); also elsewhere on the board
adr17: U4.30 (A17), U7.30 (A17); also elsewhere on the board
adr18: U4.1 (A18), U7.1 (A18); also elsewhere on the board
data0: U4.13 (DQ0), U7.13 (DQ0), U11.11 (D0); also elsewhere on the board
data1: U4.14 (DQ1), U7.14 (DQ1), U11.12 (D1); also elsewhere on the board
data2: U4.15 (DQ2), U7.15 (DQ2), U11.13 (D2); also elsewhere on the board
data3: U4.17 (DQ3), U7.17 (DQ3), U11.15 (D3); also elsewhere on the board
data4: U4.18 (DQ4), U7.18 (DQ4), U11.16 (D4); also elsewhere on the board
data5: U4.19 (DQ5), U7.19 (DQ5), U11.17 (D5); also elsewhere on the board
data6: U4.20 (DQ6), U7.20 (DQ6), U11.18 (D6); also elsewhere on the board
data7: U4.21 (DQ7), U7.21 (DQ7), U11.19 (D7); also elsewhere on the board
/ram0sel: U4.22 (CE); also elsewhere on the board
/ram1sel: U7.22 (CE); also elsewhere on the board
/rd: U4.24 (OE), U7.24 (OE), U11.22 (OE); also elsewhere on the board
/rom0sel: U11.20 (CE); also elsewhere on the board
/wr: U4.29 (WE), U7.29 (WE); also elsewhere on the board

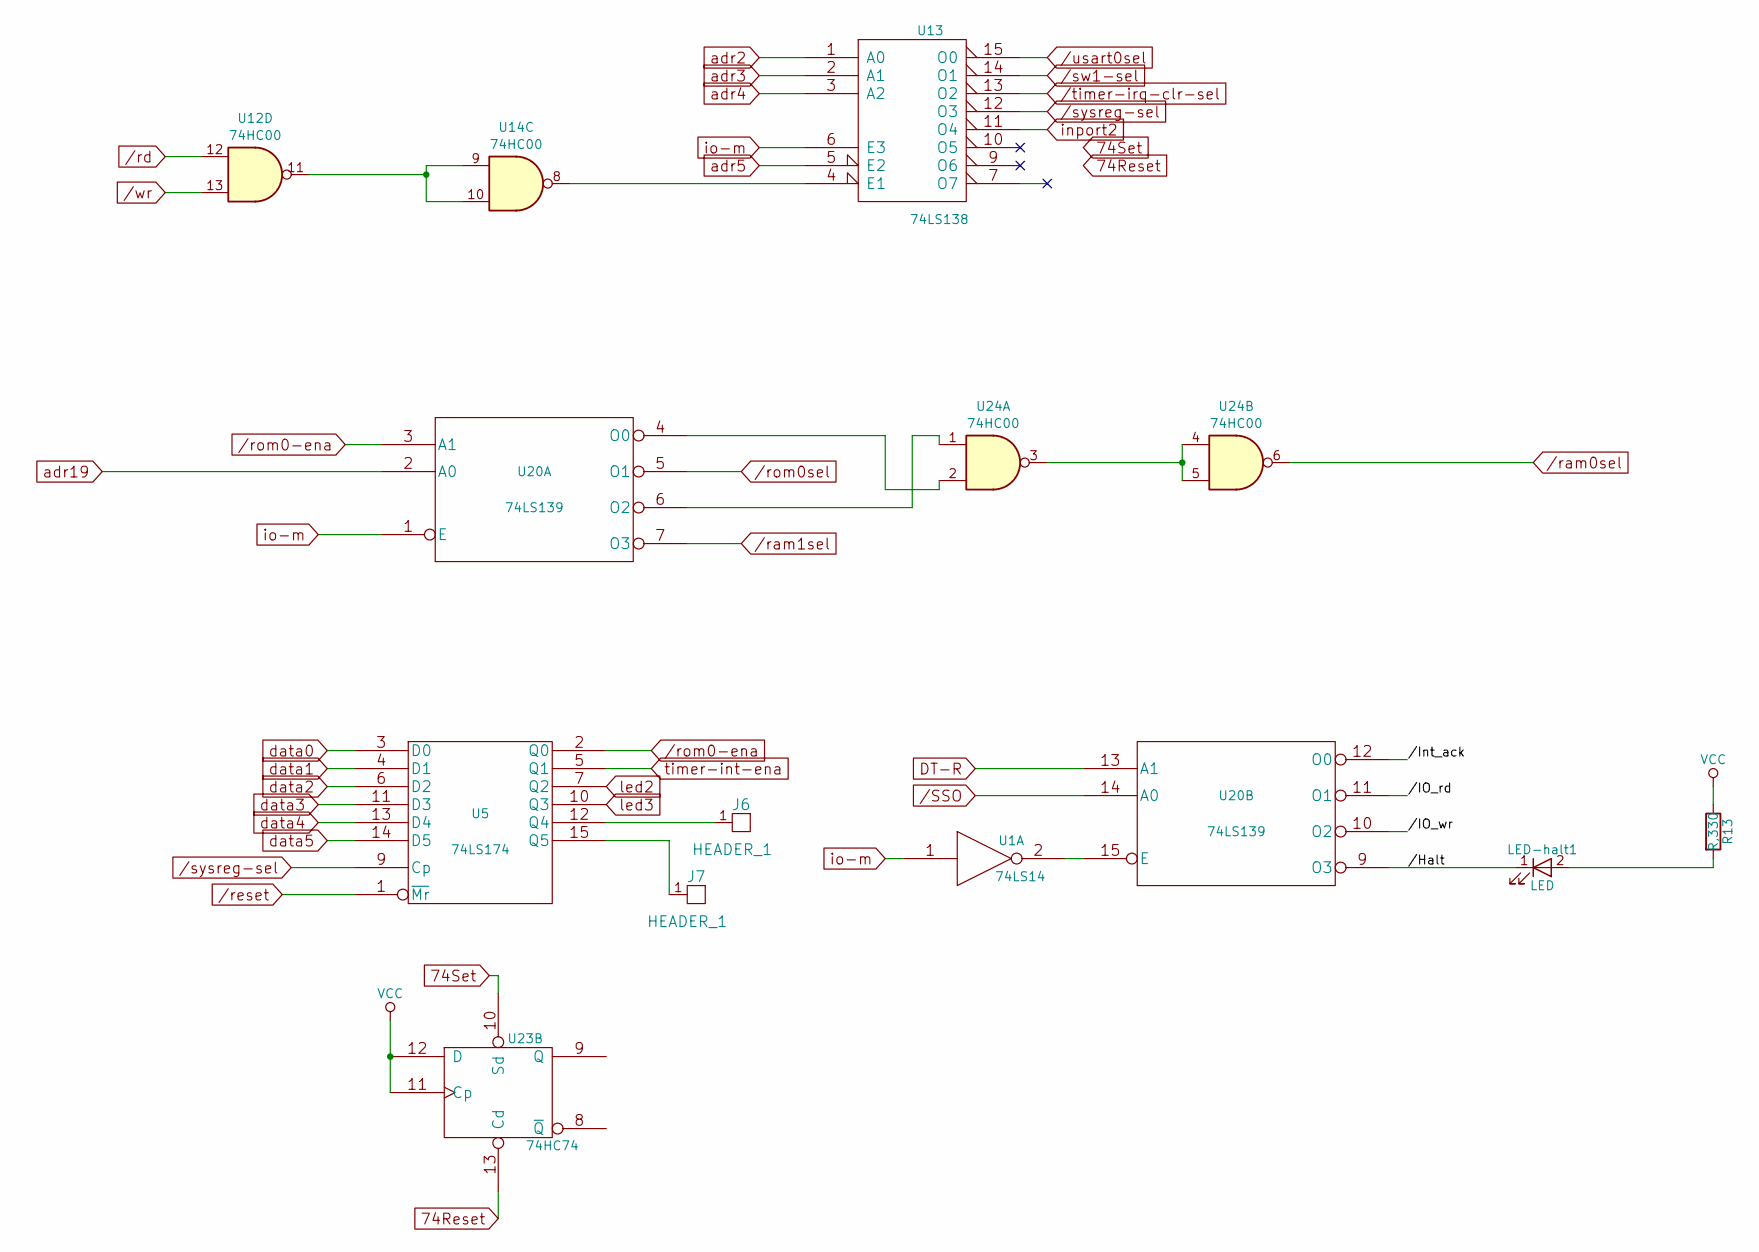
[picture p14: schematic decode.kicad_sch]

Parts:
J6, J7: HEADER_1; PinHeader_1x01_P2.54mm_Vertical
LED-halt1: LED; LED_D1.8mm_W3.3mm_H2.4mm
R13: R,330; R_Axial_DIN0207_L6.3mm_D2.5mm_P2.54mm_Vertical
U1: 74LS14; DIP-14_W7.62mm
U5: 74LS174; DIP-16_W7.62mm
U12, U14, U24: 74HC00
U13: 74LS138; DIP-16_W7.62mm
U20: 74LS139; DIP-16_W7.62mm
U23: 74HC74; DIP-14_W7.62mm

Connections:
74Reset: U23.13 (Cd)
74Set: U23.10 (Sd)
/decode//Halt: LED-halt1.1 (K), U20.9 (O3)
/decode//IO_rd: U20.11 (O1)
/decode//IO_wr: U20.10 (O2)
/decode//Int_ack: U20.12 (O0)
DT-R: U20.13 (A1); also elsewhere on the board
GND: U1.7 (GND), U5.8 (GND), U12.7 (GND), U13.8 (GND), U20.8 (GND), U23.7 (GND), U24.7 (GND); also elsewhere on the board
unnamed: LED-halt1.2 (A), R13.2
unnamed: J6.1, U5.12 (Q4)
unnamed: J7.1, U5.15 (Q5)
unnamed: U12.9, U12.10, U12.11, U14.9, U14.10
unnamed: U12.8, U13.4 (E1), U14.8
unnamed: U20.4 (O0), U24.2
unnamed: U20.6 (O2), U24.1
unnamed: U1.2, U20.15 (E)
unnamed: U24.3, U24.4, U24.5
VCC: R13.1, U1.14 (VCC), U5.16 (VCC), U12.14 (VCC), U13.16 (VCC), U20.16 (VCC), U23.11 (Cp), U23.12 (D), U23.14 (VCC), U24.14 (VCC); also elsewhere on the board
adr2: U13.1 (A0); also elsewhere on the board
adr3: U13.2 (A1); also elsewhere on the board
adr4: U13.3 (A2); also elsewhere on the board
adr5: U13.5 (E2); also elsewhere on the board
adr19: U20.2 (A0); also elsewhere on the board
data0: U5.3 (D0); also elsewhere on the board
data1: U5.4 (D1); also elsewhere on the board
data2: U5.6 (D2); also elsewhere on the board
data3: U5.11 (D3); also elsewhere on the board
data4: U5.13 (D4); also elsewhere on the board
data5: U5.14 (D5); also elsewhere on the board
inport2: U13.11 (O4); also elsewhere on the board
io-m: U1.1, U13.6 (E3), U20.1 (E); also elsewhere on the board
led2: U5.7 (Q2); also elsewhere on the board
led3: U5.10 (Q3); also elsewhere on the board
timer-int-ena: U5.5 (Q1); also elsewhere on the board
/SSO: U20.14 (A0); also elsewhere on the board
/ram0sel: U24.6; also elsewhere on the board
/ram1sel: U20.7 (O3); also elsewhere on the board
/rd: U12.12; also elsewhere on the board
/reset: U5.1 (~Mr); also elsewhere on the board
/rom0-ena: U5.2 (Q0), U20.3 (A1); also elsewhere on the board
/rom0sel: U20.5 (O1); also elsewhere on the board
/sw1-sel: U13.14 (O1); also elsewhere on the board
/sysreg-sel: U5.9 (Cp), U13.12 (O3)
/timer-irq-clr-sel: U13.13 (O2); also elsewhere on the board
/usart0sel: U13.15 (O0); also elsewhere on the board
/wr: U12.13; also elsewhere on the board

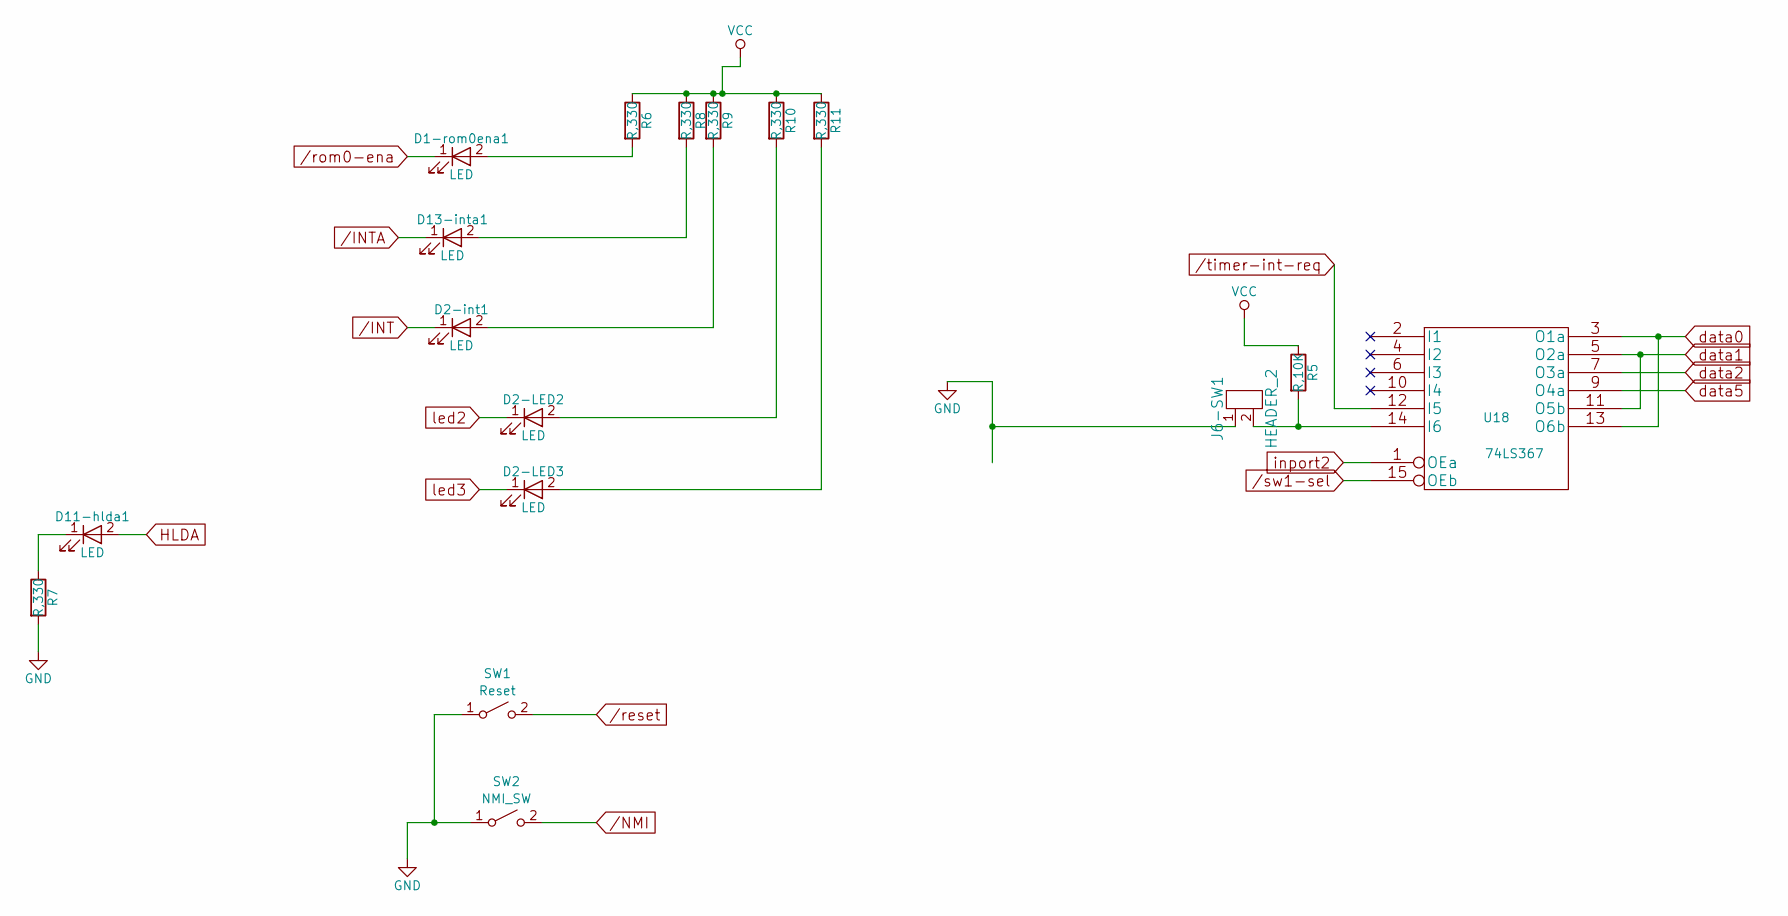
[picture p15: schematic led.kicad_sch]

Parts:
D1-rom0ena1, D2-LED2, D2-LED3, D2-int1, D11-hlda1, D13-inta1: LED; LED_D1.8mm_W3.3mm_H2.4mm
J6-SW1: HEADER_2; PinHeader_2x01_P2.54mm_Vertical
R5: R,10K; R_Axial_DIN0207_L6.3mm_D2.5mm_P2.54mm_Vertical
R6, R7, R8, R9, R10, R11: R,330; R_Axial_DIN0207_L6.3mm_D2.5mm_P2.54mm_Vertical
SW1: Reset; SW_PUSH_1P1T_6x3.5mm_H5.0_APEM_MJTP1250
SW2: NMI_SW; SW_PUSH_1P1T_6x3.5mm_H5.0_APEM_MJTP1250
U18: 74LS367; DIP-16_W7.62mm

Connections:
GND: J6-SW1.1, R7.2, SW1.1 (A), SW2.1 (A), U18.8 (GND); also elsewhere on the board
HLDA: D11-hlda1.2 (A); also elsewhere on the board
unnamed: D1-rom0ena1.2 (A), R6.2
unnamed: D2-LED2.2 (A), R10.2
unnamed: D2-LED3.2 (A), R11.2
unnamed: D2-int1.2 (A), R9.2
unnamed: D11-hlda1.1 (K), R7.1
unnamed: D13-inta1.2 (A), R8.2
unnamed: J6-SW1.2, R5.2, U18.14 (I6)
VCC: R5.1, R6.1, R8.1, R9.1, R10.1, R11.1, U18.16 (VCC); also elsewhere on the board
data0: U18.3 (O1a), U18.13 (O6b); also elsewhere on the board
data1: U18.5 (O2a), U18.11 (O5b); also elsewhere on the board
data2: U18.7 (O3a); also elsewhere on the board
data5: U18.9 (O4a); also elsewhere on the board
inport2: U18.1 (OEa); also elsewhere on the board
led2: D2-LED2.1 (K); also elsewhere on the board
led3: D2-LED3.1 (K); also elsewhere on the board
/INT: D2-int1.1 (K); also elsewhere on the board
/INTA: D13-inta1.1 (K); also elsewhere on the board
/NMI: SW2.2 (B); also elsewhere on the board
/reset: SW1.2 (B); also elsewhere on the board
/rom0-ena: D1-rom0ena1.1 (K); also elsewhere on the board
/sw1-sel: U18.15 (OEb); also elsewhere on the board
/timer-int-req: U18.12 (I5); also elsewhere on the board

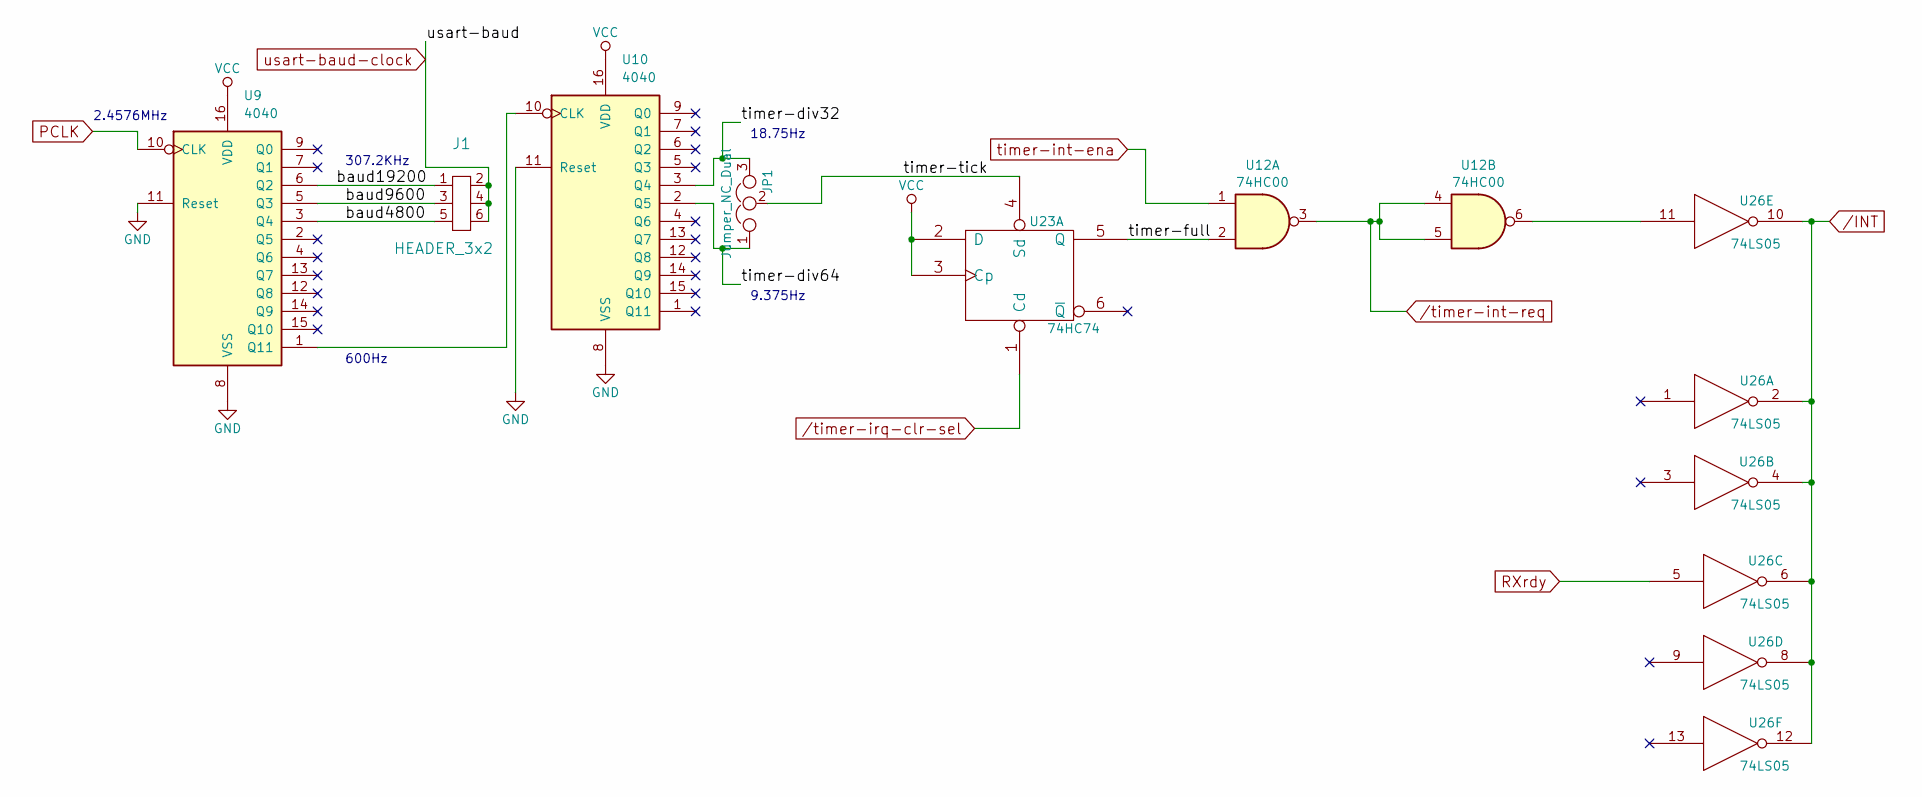
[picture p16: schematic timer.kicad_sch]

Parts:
J1: HEADER_3x2; PinHeader_2x03_P2.54mm_Vertical
JP1: Jumper_NC_Dual; PinHeader_1x03_P2.54mm_Vertical
U9, U10: 4040; DIP-16_W7.62mm
U12: 74HC00
U23: 74HC74; DIP-14_W7.62mm
U26: 74LS05; DIP-14_W7.62mm

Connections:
/timer/baud4800: J1.5, U9.3 (Q4)
/timer/baud9600: J1.3, U9.5 (Q3)
/timer/baud19200: J1.1, U9.6 (Q2)
/timer/timer-div32: JP1.3, U10.3 (Q4)
/timer/timer-div64: JP1.1, U10.2 (Q5)
/timer/timer-full: U12.2, U23.5 (Q)
/timer/timer-tick: JP1.2, U23.4 (Sd)
GND: U9.8 (VSS), U9.11 (Reset), U10.8 (VSS), U10.11 (Reset), U12.7 (GND), U23.7 (GND), U26.7 (GND); also elsewhere on the board
unnamed: U9.1 (Q11), U10.10 (CLK)
unnamed: U12.6, U26.11
unnamed 48: U12.9, U12.10; also elsewhere on the board
unnamed 49: U12.8; also elsewhere on the board
PCLK: U9.10 (CLK); also elsewhere on the board
RXrdy: U26.5; also elsewhere on the board
VCC: U9.16 (VDD), U10.16 (VDD), U12.14 (VCC), U23.2 (D), U23.3 (Cp), U23.14 (VCC), U26.14 (VCC); also elsewhere on the board
timer-int-ena: U12.1; also elsewhere on the board
usart-baud-clock: J1.2, J1.4, J1.6; also elsewhere on the board
/INT: U26.2, U26.4, U26.6, U26.8, U26.10, U26.12; also elsewhere on the board
/timer-int-req: U12.3, U12.4, U12.5; also elsewhere on the board
/timer-irq-clr-sel: U23.1 (Cd); also elsewhere on the board

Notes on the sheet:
600Hz
18.75Hz
2.4576MHz
9.375Hz
307.2KHz

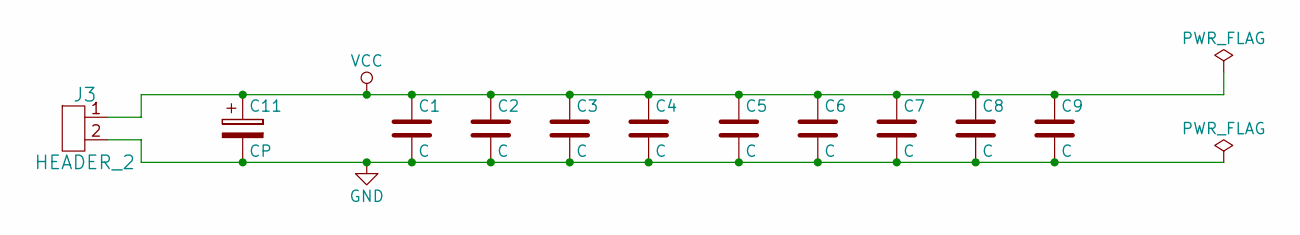
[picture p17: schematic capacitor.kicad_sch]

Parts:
C1, C2, C3, C4, C5, C6, C7, C8, C9: C; C_Disc_D3.0mm_W2.0mm_P2.50mm
C11: CP; C_Disc_D3.4mm_W2.1mm_P2.50mm
J3: HEADER_2; PinHeader_2x01_P2.54mm_Vertical

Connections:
GND: C1.2, C2.2, C3.2, C4.2, C5.2, C6.2, C7.2, C8.2, C9.2, C11.2, J3.2; also elsewhere on the board
VCC: C1.1, C2.1, C3.1, C4.1, C5.1, C6.1, C7.1, C8.1, C9.1, C11.1, J3.1; also elsewhere on the board

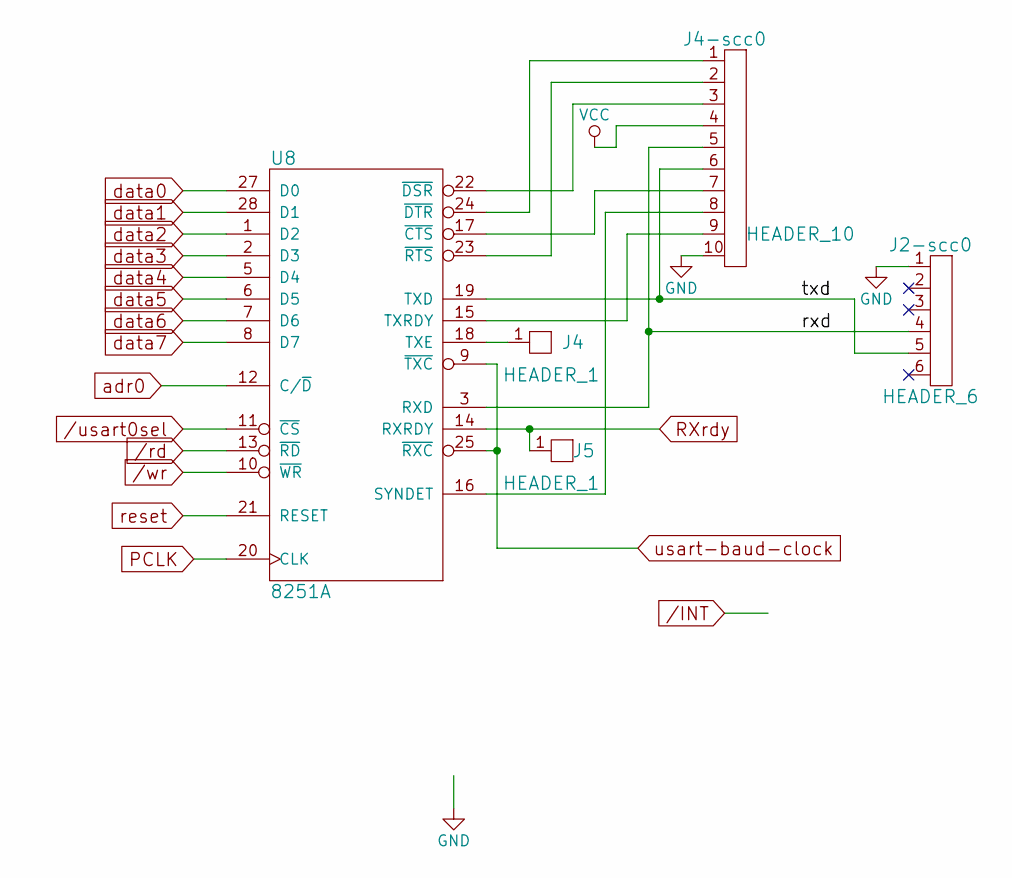
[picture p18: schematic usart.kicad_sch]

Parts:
J2-scc0: HEADER_6; PinHeader_1x06_P2.54mm_Vertical
J4, J5: HEADER_1; PinHeader_1x01_P2.54mm_Vertical
J4-scc0: HEADER_10; PinHeader_2x05_P2.54mm_Vertical
U8: 8251A; DIP-28_W15.24mm

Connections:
/usart/rxd: J2-scc0.4, J4-scc0.5, U8.3 (RXD)
/usart/txd: J2-scc0.5, J4-scc0.6, U8.19 (TXD)
GND: J2-scc0.1, J4-scc0.10, U8.4 (GND); also elsewhere on the board
unnamed: J4-scc0.8, U8.16 (SYNDET)
unnamed: J4.1, U8.18 (TXE)
unnamed: J4-scc0.9, U8.15 (TXRDY)
unnamed: J4-scc0.7, U8.17 (~CTS)
unnamed: J4-scc0.3, U8.22 (~DSR)
unnamed: J4-scc0.1, U8.24 (~DTR)
unnamed: J4-scc0.2, U8.23 (~RTS)
PCLK: U8.20 (CLK); also elsewhere on the board
RXrdy: J5.1, U8.14 (RXRDY); also elsewhere on the board
VCC: J4-scc0.4, U8.26 (VCC); also elsewhere on the board
adr0: U8.12 (C/~D); also elsewhere on the board
data0: U8.27 (D0); also elsewhere on the board
data1: U8.28 (D1); also elsewhere on the board
data2: U8.1 (D2); also elsewhere on the board
data3: U8.2 (D3); also elsewhere on the board
data4: U8.5 (D4); also elsewhere on the board
data5: U8.6 (D5); also elsewhere on the board
data6: U8.7 (D6); also elsewhere on the board
data7: U8.8 (D7); also elsewhere on the board
reset: U8.21 (RESET); also elsewhere on the board
usart-baud-clock: U8.9 (~TXC), U8.25 (~RXC); also elsewhere on the board
/rd: U8.13 (~RD); also elsewhere on the board
/usart0sel: U8.11 (~CS); also elsewhere on the board
/wr: U8.10 (~WR); also elsewhere on the board

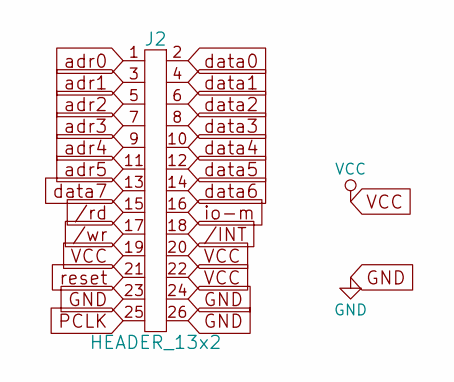
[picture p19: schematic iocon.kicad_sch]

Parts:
J2: HEADER_13x2; PinHeader_2x13_P2.54mm_Vertical

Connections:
GND: J2.23, J2.24, J2.26; also elsewhere on the board
PCLK: J2.25; also elsewhere on the board
VCC: J2.19, J2.20, J2.22; also elsewhere on the board
adr0: J2.1; also elsewhere on the board
adr1: J2.3; also elsewhere on the board
adr2: J2.5; also elsewhere on the board
adr3: J2.7; also elsewhere on the board
adr4: J2.9; also elsewhere on the board
adr5: J2.11; also elsewhere on the board
data0: J2.2; also elsewhere on the board
data1: J2.4; also elsewhere on the board
data2: J2.6; also elsewhere on the board
data3: J2.8; also elsewhere on the board
data4: J2.10; also elsewhere on the board
data5: J2.12; also elsewhere on the board
data6: J2.14; also elsewhere on the board
data7: J2.13; also elsewhere on the board
io-m: J2.16; also elsewhere on the board
reset: J2.21; also elsewhere on the board
/INT: J2.18; also elsewhere on the board
/rd: J2.15; also elsewhere on the board
/wr: J2.17; also elsewhere on the board

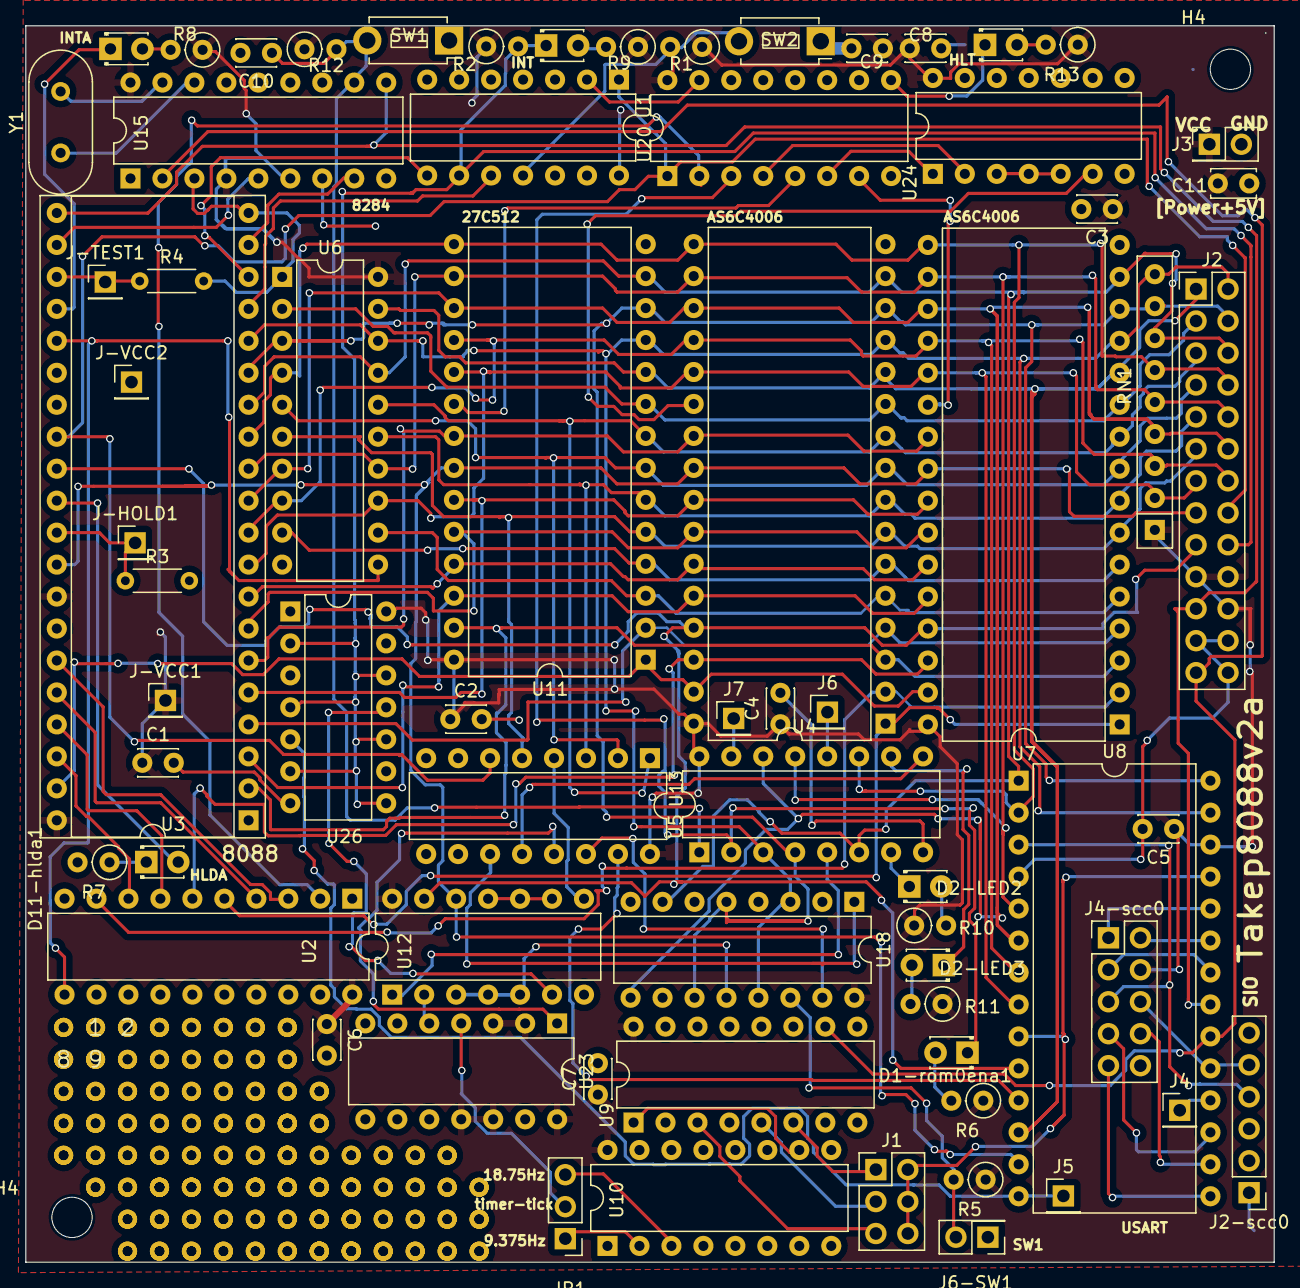
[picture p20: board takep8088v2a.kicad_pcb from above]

Board: 2 copper layers, 99.2 x 98.2 mm, 167 parts (0 on the bottom side), 105 nets.

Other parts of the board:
1, 2, 3, 4, 5, 6, 7, 8, 9, 10, 11, 12, 13, 14, 15, 16, 17, 18, 19, 20, 21, 22, 23, 24, 25, 26, 27, 28, 29, 30, 31, 32, 33, 34, 35, 36, 37, 38, 39, 41, 42, 43, 44, 45, 46, 47, 48, 49, 50, 51, 52, 53, 54, 55, 56, 57, 58, 59, 60, 61, 62, 63, 64, 65, 66, 67, 68, 69, 70, 71, 72, 73, 74, 75, 76, 77, 78, 79, 81, 82, 83, 84, 85, 86, 87, 88, 89, 90, 91, 92, 93, 94, 95, 96, 97, 98: (no value)
H4, H4#2: MountingHole; MountingHole_3.2mm_M3

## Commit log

2026-03-20 Expand README with specs and circuit details
    Added detailed specifications and circuit information for the 8088 Single Board Computer.
2026-03-20 Board Photo upload
2026-03-20 Update README with board details and image
    Added board section with jumper information and image.
2026-03-20 Update README with SIO 8251 and timer information
    Added details about SIO 8251 and free-running timer settings.
2026-03-20 Update README with wire design notes and HOLD info
    Added notes about wire connections and HOLD functionality.
2026-03-22 Fix LED indicator description in README

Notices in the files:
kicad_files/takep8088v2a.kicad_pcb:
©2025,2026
